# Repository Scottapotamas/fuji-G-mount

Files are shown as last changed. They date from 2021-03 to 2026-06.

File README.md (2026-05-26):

# Fujifilm G Mount
The Fujifilm G Mount is used by the Fujifilm GFX line of digital medium format mirrorless cameras.

Since the announcement in 2016, the GF lens ecosystem has been gaining popularity due to the superb optical performance, high megapixel camera bodies (GFX100), and low cost (well... compared to other MFD systems).

One minor challenge compared to most existing lens ecosystems - **all GF lenses are fly-by-wire**. Sensing user interaction with the aperture or focus rings, and commanding the iris and focus mechanisms will require computer control. Additionally, lenses such as the 110mm f2 and 250mm f4 have floating optical elements which require power/control from the body in order to become optically valid.

____

My long-term photography/hobby goals are rather ambitious; *build a film camera from scratch using modern lenses*. A 120 'body' for my GF lenses feels like the right kind of wrong...

## Aims

- [x] Document the mechanics of the G Mount sufficiently to create native-compatible mounts from scratch.
- Reverse-engineer & document the communications between the lens and body:
  - [x] Pinout for the electrical contacts in the lens mount,
  - [ ] Power supply requirements for lenses,
  - [x] Sniff the communications between the lens and camera, and document any specifics if possible.
- [ ] Write a library capable of parsing lens data (in both directions) in real-time.
- [x] Create an interface PCB which pretends to be a GFX camera - powers and controls an attached lens, can read lens info and focus/iris ring feedback.

## Prior Art?

At time of writing, no publicly available information about the mount's mechanics could be found other than the flange distance and internal diameter.

Similarly, any electrical interface or protocol information is not in the public domain.

> There's a good chance the Fuji X-mount uses a similar protocol or structure. Couldn't find any information for that either...

Several active (3rd party) lens adaptors *are* on the market, allowing smart control over Canon EF, Contax C645, and others. Therefore we can guess at least three different groups have successful implementations with varying levels of functionality.

## What's the plan

- [x] Buy a genuine Fujifilm extension tube [MCEX-45G WR](https://fujifilm-x.com/global/products/accessories/mcex-45g-wr/) to act as a ground-truth mechanical mount.
   - The absurd $500AUD pricepoint is painful, but won't risk my camera or lenses. I managed to get 25% off MSRP.
   - I could use one of the $150AUD Viltrox clone extension tubes later on, but I want an accurate first-party reference to build against.
- [x] Create detailed 3D models of the male and female mount geometries, identify screws/springs/gaskets used. Refer [`/mechanical`](/mechanical).
- [x] Dissemble the extension tube, design a replacement 'cylinder' to mount the genuine mounting faces onto. Or just seal it's fate and drill a hole in the adaptor...
   - Expose the lens and body electrical contacts through a loom or connector - ideally each side can be separated at will for easier debugging.
- [x] Map the electrical connections between the body and lens, create rough specs for power rails, determine the style of communication and electrical implementation(s) in use. Refer [`/electrical`](/electrical).
- [x] Assuming no strange electrical interfaces are used, connect the logic analyser/scope and build out a corpus of messages sent between the lens and body.
  - Refer [`/protocol`](/protocol) for notes.
  - Capture control ring, iris closure, focus motor on GF110 to compare against 45mm findings.
- [ ] Write a basic library implementation with unit tests against captured packets
   - [ ] Connect a micro running the library in real-time to the body, see what works/doesn't.
   - [ ] Connect micro to lens, see if setting iris or focus is possible

## What have we learnt

- Enough to successfully make a [GF mount adapter for the Fuji MK series S35 cine-zooms](https://github.com/Scottapotamas/fuji-mk-zoom-to-GF-mount).
- Protocol behaviour for a subset of packets: 
  - Aperture index and relative focus ring rotations sent from the lens to the camera
  - Closing the iris
  - Commanding absolute focus motor position
  - Some hazy details on the packet shapes

# References & Acknoledgements

- A [large mirror of firmware updates](https://u.pcloud.link/publink/show?code=kZRGzJXZA5zjOTgVm2FJjdvTIG1UekBLWefV#/filemanager?folder=7261419858) here by [Manzur Fahim on DPreview](https://www.dpreview.com/forums/threads/fujifilm-gf-lens-firmware-not-available-anymore.4824834/post-68549141).

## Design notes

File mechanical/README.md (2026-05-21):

# GF Mount Notes

This section covers the mechanical specifics involved in mounting a lens/body to existing GF mount lenses/bodies.

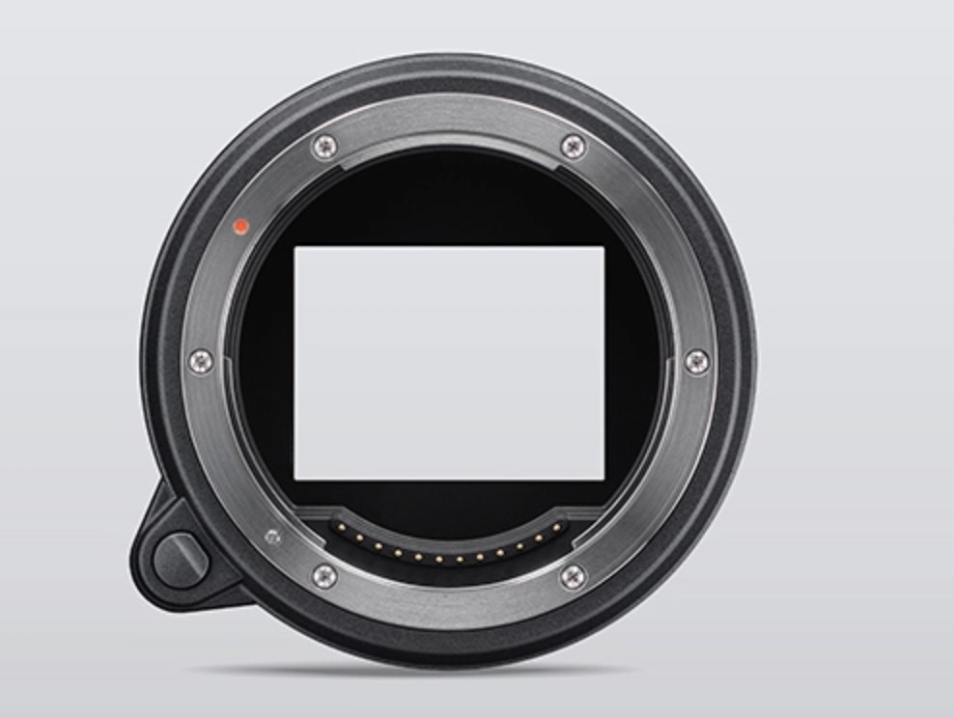
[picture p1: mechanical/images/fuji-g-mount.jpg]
fuji-g-mount


Where possible, 3D models strive for accuracy against first-party geometry, but due to the complex nature of some parts there is no guarantee of dimensional or tolerance perfection.

Additionally, while the models for machinable parts are accurate, little is known of the specification of the various screws as most are smaller than I'm able to accurately identify.

>  Custom fastener choice is recommended if mounting to custom assemblies.

## Mounting Faces

Measured off a disassembled MCEX-45, the front and back face 'flange' parts are all that's required to mechanically couple with existing GF mount hardware.

The design and manufacture of the external mounting faces with the 45mm extension tube is externally identical to the geometry on the GF45 and GFX50R.

> Models match first party parts more accurately than required for 3rd party mounts. The internal geometry and stepped internal faces can be simplified.

The two mating parts were tested for mechanical compatibility and tolerance with a physics simulation, and tolerances in the mated 3D models match the physical mounts checked with a spring-steel feeler-gauge.

Renders below:

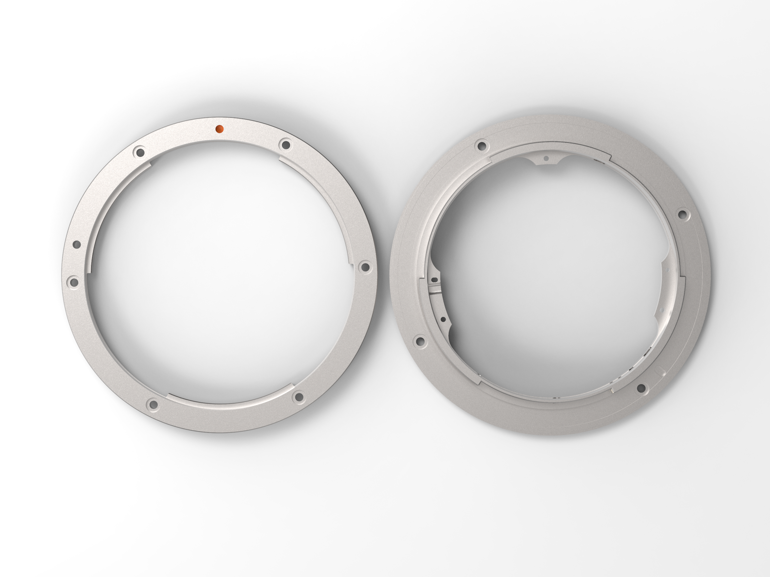
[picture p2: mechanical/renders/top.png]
top


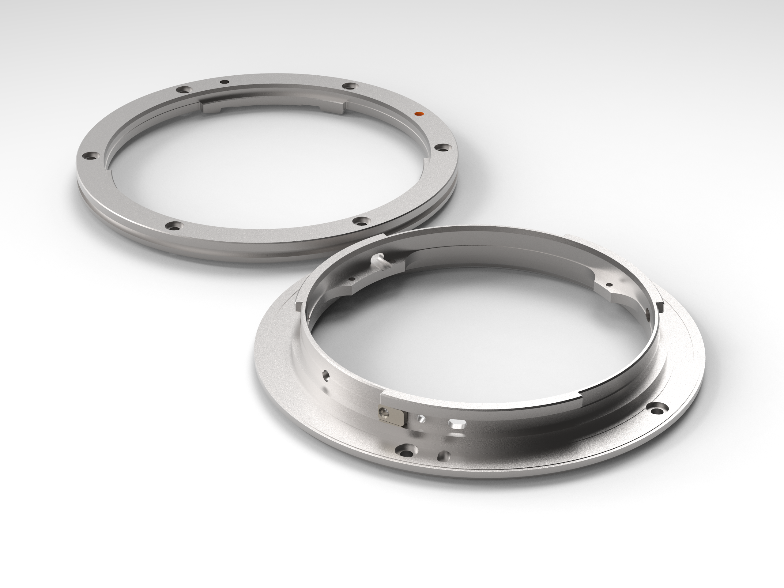
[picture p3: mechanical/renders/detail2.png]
detail2


Based on the part's surface finish and geometry, it's assumed that the lens mount 'male' is 4-axis machined, or likely turned on a lathe with live tooling.

The body mount has internal features which suggest casting, with post-machining of the front face and internal + external cylindrical faces.

The body mount has a thin (0.3 mm) stainless shim with bent metal tabs to provide preload against a mating lens. This shim is modelled but does not feature accurate tab bends (just do it by hand).

As a general note, it's probably cheaper to cannibalise the mounts from first party extension tubes, than it would be to send a pair for CNC machining due to the complicated geometry.

> When I 3D printed these they mounted fine, but the tolerances were a bit tight for brass machined mounts.
>
> Might be worth spot-checking some of the critical diameters again to better understand expected tolerances 

## Electrical Contacts

The contacts are also provided as a reference drawing, and in DXF format suitable for use with PCB design software to create custom pin array boards.

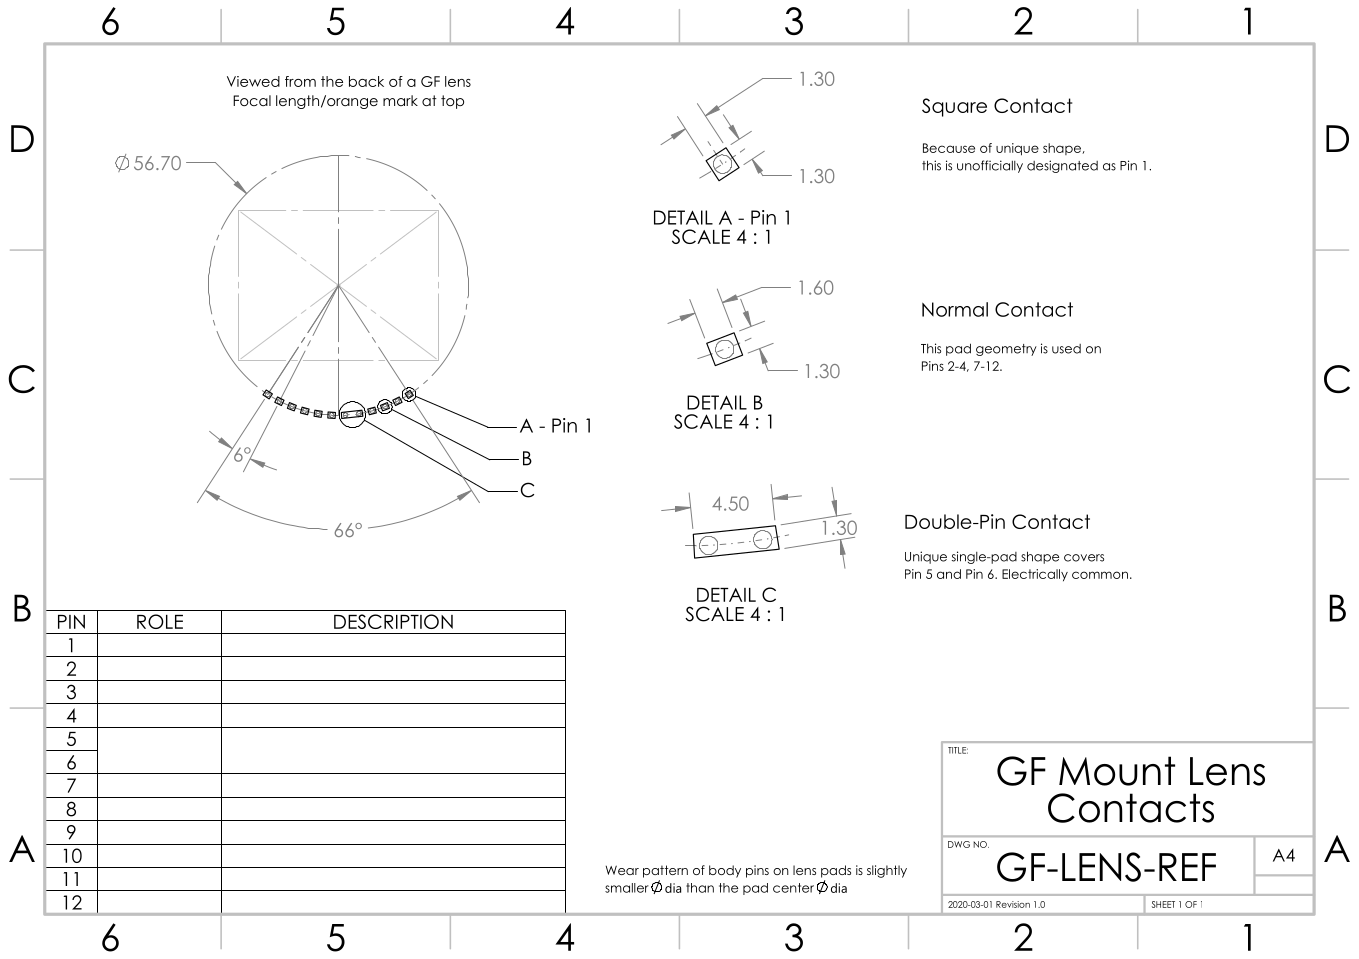
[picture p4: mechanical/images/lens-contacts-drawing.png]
lens-contacts-drawing


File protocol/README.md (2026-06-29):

# GF Protocol Notes

Sniffing of the communications between the body and lens is achieved with a modified MCEX-45G, and builds from the basic electrical analysis described in [the electrical README](/electrical).

This document has been reworked several times as my understanding of the protocol has developed. Apologies for mixed 'exploratory log' and 'findings' which sometimes includes extra information.

**Logic Analyser Captures**

Useful trace files are committed to the `captures` folder. Most analysis was done against the GF45 dumps, with later checks against the GF110.

These files require Saleae's Logic 2 tool for viewing. It's freely available for download on their website [here](https://www.saleae.com/downloads/).

Specific packets or sections of interest are converted into a more digestible form and are saved in `/packet-captures` as hex encoded binary files.

# SPI Communication

We can make the assumption about the specific IN/OUT pins because there ares in the logic captures which show one-way initial send packets, and occasional one-way responses.

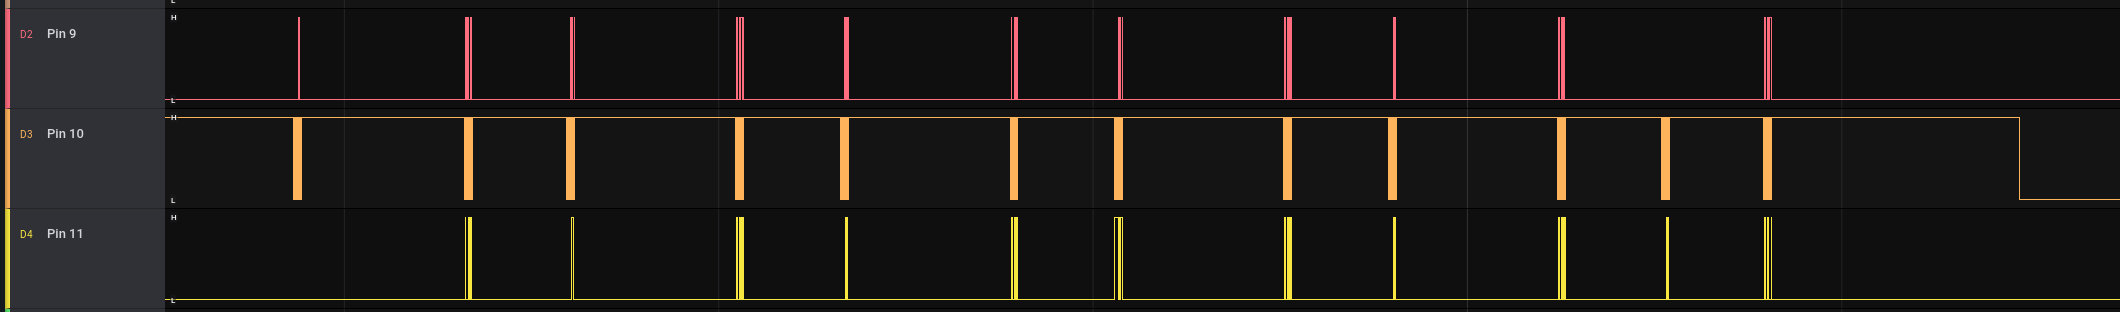
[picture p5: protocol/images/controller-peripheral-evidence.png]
controller-peripheral-evidence


Based on this, we can assume that:

- Pin 9 is body's DATA OUT line.
- Pin 10 is a 1.5MHz SPI-style clock signal.
- Pin 11 is the body's DATA IN line.

With this in mind, we now aim to identify the properties of the communications bus and determine that it uses typical SPI instead of some Fuji special sauce.

- A transaction consists of 32-bits at minimum
  - Almost all transactions are 32-bits long.
  - During startup, a pair of 1048-bit long transactions occur with a 3ms gap - these are the longest identified transactions.
  - As the division of  `1048` and the potential bits-per-transfer should be an integer, we can reasonably throw out `16` and `32` bit transfer sizes.

By manually inspecting logic captures, one example section helps determine the clock behaviour.

- The clock is high when inactive (CPOL = 1).
- Data is valid on the clock's trailing edge (CPHA = 1)
  - Demonstrated by the edges on the first falling edge, and on falling edges aligned to 8-bit sequences.
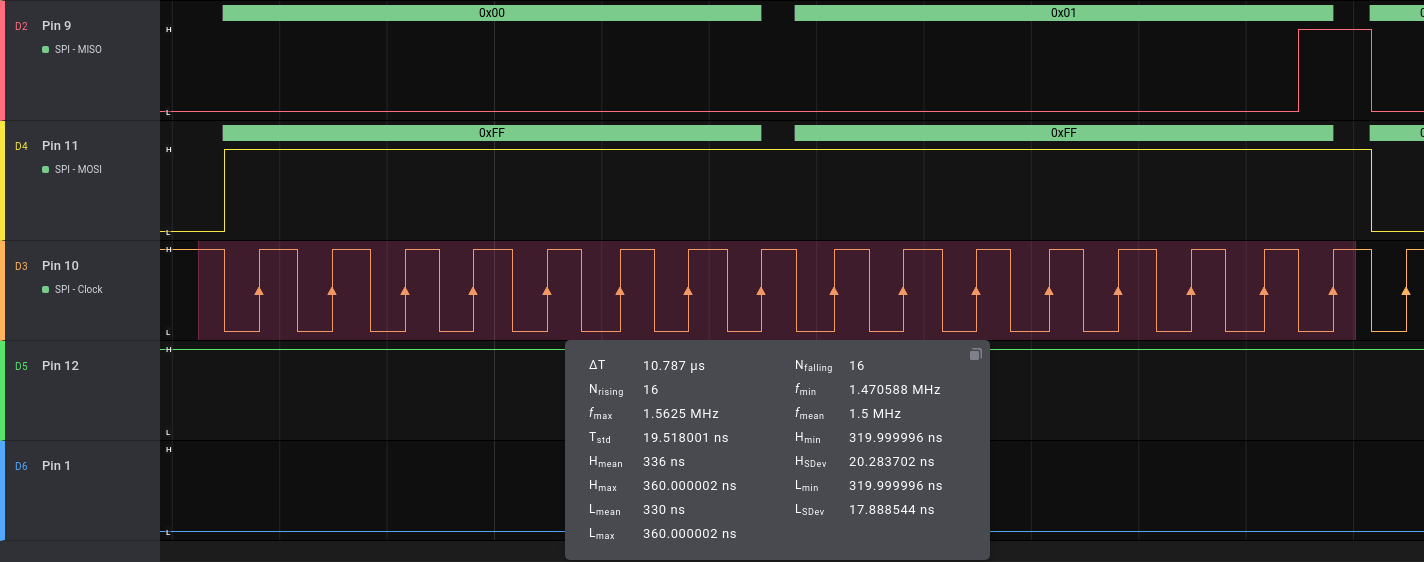
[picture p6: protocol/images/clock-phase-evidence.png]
clock-phase-evidence
    

As with typical SPI busses working with bidirectional transfers, there a fairly visible 1-packet delay between the body writing a field and the lens response.

When I'm listing tx/rx pairs in a given transaction in this document, that offset isn't included unless specified.

# Packet Exploration

While I've done this against/for the G-mount, poking at lens firmware update files and packet captures from [X-mount by Feiko Nanninga aka 'clonejo'](https://codeberg.org/clonejo/fuji-mount) allowed me to compare behaviour.

## Packet Structure

In wire-order most packets are 4-bytes of the form `payload payload command status` where useful payloads are typically big-endian signed 16-bit values or low value indexes.

Throughout the docs I've been treating the seemingly unstable last byte as some kind of checksum byte, but it's actually a structure with an extra field which is important for several command types.

### Message/Command

The command byte (third byte sent over the wire) includes an 'ack' flag at bit 7, i.e. `cmd | 0x80`, demonstrated on most currently known packets between tx and rx.

The total group of unique command bytes observed is below, entries with listed CMD or ACK values are in captured files. Currently the possible `0x00` command has not been observed.

| CMD | ACK/Response | Decode status |
| --- | --- | --- |
| — | `0x80` | Transport/status, not really decoded |
| `0x05` | `0x85` | Not documented/decoded |
| `0x06` | `0x86` | Not documented/decoded |
| `0x07` | | Not documented/decoded |
| `0x08` | `0x88` | Aperture/Focus and lens state feedback |
| `0x09` | `0x89` | Longer lens status bursts, not understood |
| `0x10` | `0x90` | Not documented/decoded |
| `0x0c` | `0x8c` | Aperture/focus control ring, mostly decoded. |
| `0x0f` | `0x8f` | Not decoded |
| `0x15` | `0x95` | Focus motor, mostly decoded |
| `0x16` | `0x96` | Not documented/decoded |
| `0x18` | `0x98` | Aperture setpoint, mostly decoded |
| `0x20` | `0xa0` | OIS. Not documented/decoded |
| `0x25` | | Not documented/decoded |
| `0x28` | `0xa8` | Not documented/decoded |
| `0x2a` | `0xaa` | Not documented/decoded |
| `0x32` | | Not documented/decoded |
| `0x3c` | | Not documented/decoded |
| `0x3f` | `0xbf` | Execute/latch, mostly decoded |

### Status Byte

Originally I was calling this a checksum due to how unstable it appeared across packets. Since then it's known to include some stateful information.

Using all the captured packets, de-duplicating and then sorting on 'command byte' and payload to find different header bytes for the same packet.

- Also filtered out all 'readout' packets that are an artifact of the SPI behaviour `00 00 00 00`.
- Assuming packets from the body and lens use the same behaviour, but the corpus tracks which device/trace the packets are seen in.

Looking over the headers, there were some under-represented bits on repeated packets with different final-bytes.

**Bit 0 is always low.** This seems to hold for *all* transactions I've captured (89,984 at time of observation). 

Luckily,  `09 00 88`  shows that **rx and tx directions can have the same final byte for an identical payload** it's less likely there's a 'camera' or 'lens' style send/recv bit in the field. This also means it's less likely that both sides are maintaining some shared incremental packet count.

The focus and iris settings use the same `0c` command byte, but when looking at the **top two bits** of the last byte, 

- Iris ring `0x0c` packets are always(?) `upper = 0` across 100+ examples.
- Focus ring `0x0c` packets are always(?) `upper = 2` across 600+ examples.
- For focus motor `0x15` packets, the upper bits evenly distribute with `00`/`01`/`10` but never `11`. 
- Execute/sync commands are `11`.

Looking at behaviour around 'most understood' packets for iris and focus there is a fairly obvious pattern in the remaining bits:

| Direction | CMD | Prefix | Upper-2b values | Final bits 1..5 values |
| --- | --- | --- | --- | --- |
| RX | `0x0c` | `00 02 0c` | 2, 0 | `1a`, `19` |
| RX | `0x0c` | `00 03 0c` | 2, 0 | `0a`, `09` |
| TX | `0x0c` | `00 00 0c` | 2, 0 | `19`, `18` |
| RX/TX | `0x15` | `01 f4 15` | 0, 2 | `0c`, `0d` |
| RX/TX | `0x15` | `03 6b 15` | 0, 2 | `1d`, `1e` |
| RX/TX | `0x15` | `01 23 15` | 1, 2 | `11`, `11` |

The table shows that with the upper bits taken into account, the remaining data in the trailing byte has a stable value and a one-bit field that varies.

Looking at the larger set of captures, only 80 of 5153 deduplicated packets have multiple tail byte options for an otherwise identical packet. When taking the upper two bits into consideration, the remaining 5 bits have fewer variations and they aren't random as expected for a signature or checksum.

This immediately **rules out sequence numbering** or global counting behaviours. ~~And I'm now convinced the remaining field(s) do not represent any kind of checksum or signature.~~

Looking over the full set of packets, the remaining byte's bit 1 (or bit 0 of the 5-bit field) seems to impact the largest number of packets, responsible for the variation in 45 of 80 relevant packet examples. So pulling this bit out during review/parsing and trying to find correlations in burst sequences or with hardware behaviours is a good next step.

| Prefix | Bits 1..5 variants | After masking bit 0 | Notes |
| --- | --- | --- | --- |
| `00 00 08` | `0x10`, `0x11` | `0x10` | Common idle/status request shape  |
| `08 00 95` | `0x14`, `0x15` | `0x14` | `0x95` ACK family |
| `08 00 89` | `0x1c`, `0x1d` | `0x1c` | `0x89` ACK family |
| `00 01 08` | `0x00`, `0x01` | `0x00` | Variant of `0x08`? |
| `00 00 0c` | `0x18`, `0x19` | `0x18` | Focus-ring / aperture-ring family |

It's a bit hard to tell right now if the next bit is independent, it's another two-bit field instead of just bit-1, or if it's a larger enum/status field? For the limited set of `88` packets here, bit 2 appears high in the longer sequences?

> I couldn't figure this out after lots of different attempts, and resorted to analysis of lens update files to find clues

The **5-bit check value is computed as a truncating sum of 5-bit chunks** over the packet, including the upper2 bits in the last byte.

```
g0 = b0[7:3]
g1 = b0[2:0] : b1[7:6]
g2 = b1[5:1]
g3 = b1[0]   : cmd[7:4]
g4 = cmd[3:0]: tag2[1]
g5 = tag2[0]
```

Then `check5 = (g0 + g1 + g2 + g3 + g4 + g5) & 0x1f`

Demonstrated on some packets:

```
00 00 08 20
tag2   = 0
check5 = 0x10
tail   = 0x20

00 02 0c 32
tag2   = 0
check5 = 0x19
tail   = 0x32

00 01 0c 92
tag2   = 2
check5 = 0x09
tail   = 0x92

00 00 3f c6
tag2   = 3
check5 = 0x03
tail   = 0xc6
```

This appears correct for 100% of `602,863` captured packets.

## Status Packets

When the camera is powered on but is otherwise sitting idle, we see a burst of transactions occur every 40ms. These packets represent the bulk of 'noise' when watching packet traces.

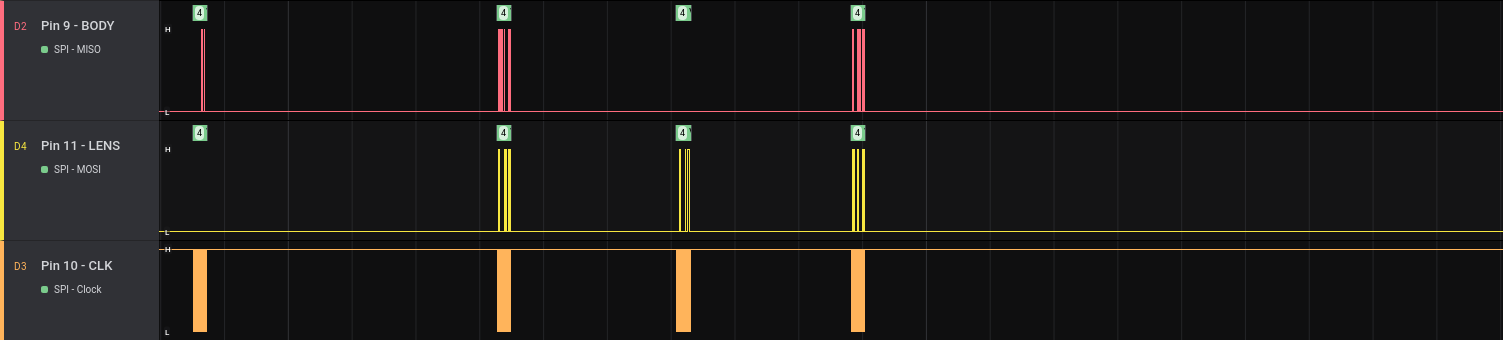
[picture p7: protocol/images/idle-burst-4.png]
idle-burst-4


| Transmission # | Camera | Lens |
| --- | --- | --- |
| 1 | `0x00 0x00 0x08 0x20` | - |
| 2 | `0x?? 0x10 0x80 0x??` | `0x08 0x00 0x88 0x32` |
| 3 | - | `0x03 0x80 0x08 0x3C` |
| 4 | `0x08 0x00 0x88 0x??` | `0x?? 0x00 0x80 0x??` |

The `0x08` packets from the body are requesting updates from the lens like aperture or focus control ring values, motor feedback etc.

This packet is also seen in the normal polling/idle traffic with tag 0, polled by the body with `00 00 08 20`. The lens-side non-ACK response should be treated as a compact status/event bitfield, but the meaning of these bits isn't entirely known yet.

The low seven bits of payload `b1` appear to identify pending follow-up requests:

| Lens response payload | Follow-up body poll | Interpretation |
| --- | --- | --- |
| `00 08`, `00 88` | `00 00 0c b2` | Focus ring / focus-control readout pending |
| `00 10`, `00 90` | `00 00 0c 30` | Aperture ring / aperture mode readout pending |
| `00 00`, `00 80` | next normal tag-0 poll | No specialised data pending |
| `00 02`, `00 82` | Status/detail path such as `0x0f` or tag2 feedback | Active/detail/actuation-status candidate |

`b1 bit7` might be a scheduler or response-phase marker. It not clear if it's a  dirty/valid/busy bit yet. ACK `0x88` tag-0 packets are transport acknowledgements and should be excluded ignored as part of the lens-state polling.

On every third burst, we have 2 additional transactions for a 6 transaction 'group'. This happens every 120ms.

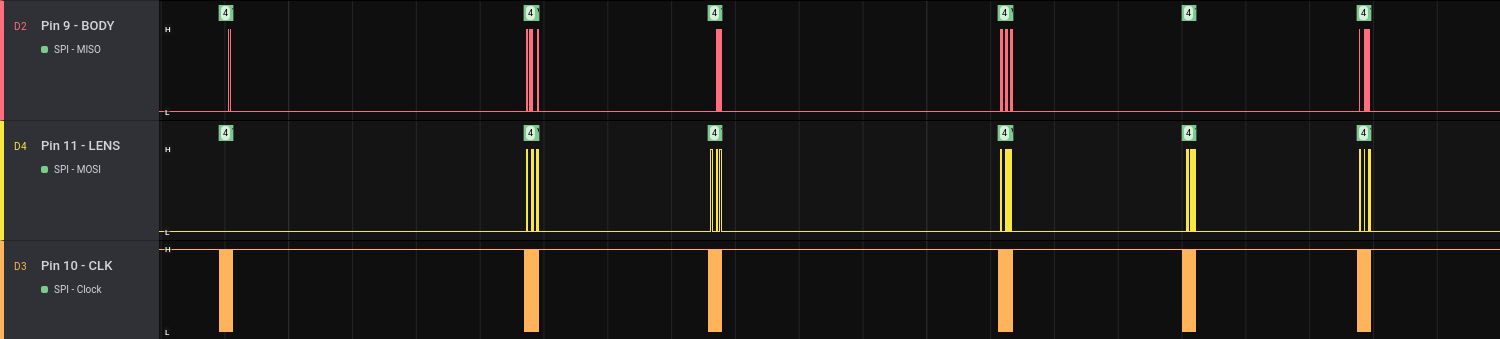
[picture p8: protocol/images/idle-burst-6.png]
idle-burst-6


These bursts add the `0x09` request `00 00 09 a6`. 

| Transmission # | Camera | Lens | Notes |
| :--- | --- | --- | --- |
| 0 | `00 00 08 20` | - | Normal `0x08` status request |
| 1 | `n 10 80 ??`  | `08 00 88 32` | Tagged transport/status + ACK |
| 2 | `00 00 09 a6` | `xx xx 08 ??` | Body requests `0x09`; lens returns normal `0x08` status due to pipeline delay |
| 3 | `n 00 88 ??`  | `n 00 89 ??`  | ACK path for previous `0x08`/`0x09` traffic |
| 4 | - | `00 xx 09 ??` | Lens returns the non-ACK `0x09` payload |
| 5 | `08 00 89 b8` | `n 00 80 ??`  | Body ACKs the `0x09` response |

The response seems to be small values, examples:

``` 
00 11 09 96
00 12 09 b8
00 13 09 98
00 14 09 ba
00 15 09 9a
00 16 09 bc
```

`00 0f`, `00 10` payloads are seen only 5 times in the capture sets, around startup transitions.

The payload value seems relatively stable/constant across most captures, when it does change it seems to toggle between adjacent values, e.g. `00 13 <-> 00 14`, `00 14 <-> 00 15` rather than jumping around.

> TODO: Work out what this actually represents?

## Identification Packets

After the camera is powered on, a series of `131B` transactions occur (each sent twice 3ms apart). Both transmissions appear to have identical payloads.

### GF45mm

The first transaction starts the first two bytes with `0x00 0x00`, and ends with `0xAF`.

The second transaction starts with `0xFF 0xFF` and ends with `0xAD`.

The payload (in hex) is:

```
4c52 3130 3641 0000 4653 534e 5730 3036
4746 3435 6d6d 4632 2e38 2052 2057 5200
0000 0000 0000 0000 0000 0000 0000 0000
0000 0000 0000 0000 0000 0000 0000 0000
0000 0000 0000 0000 0000 0000 0000 0000
3234 3033 3338 3636 3035 0156 0100 0100
0100 0100 c801 0000 0000 0000 0000 0000
0000 0000 0000 0000 0000 0000 0000 0000
```

These transactions are from the lens to the body and **describe the lens**. 

- The first section of data is ASCII: `LR106A  FSSNW006GF45mmF2.8 R WR` 
  - The first section, `LR106A` is also in the lens firmware as a string with `FSSNW006`. Refer to `/firmware/identity-strings.md`.
  - The last half is obvious obvious, the lens is officially labelled as  `GF45mmF2.8 R WR`.
- The second block of data in the payload is `2403386605 V` `È` in ASCII, which isn't immediately obvious
  - TODO work out what this data means?

### GF110mm

The first transaction starts the first two bytes with `0x00 0x00`, and ends with `0x0B`.

The second transaction starts with `0xFF 0xFF` and ends with `0x09`.

The payload (in hex) is:

```
4c52 3130 3441 0000 4653 534e 5731 3034
4746 3131 306d 6d46 3220 5220 4c4d 2057
5200 0000 0000 0000 0000 0000 0000 0000
0000 0000 0000 0000 0000 0000 0000 0000
0000 0000 0000 0000 0000 0000 0000 0000
3035 4330 3030 3234 0000 0160 0110 0110
0110 0110 c801 0000 0000 0000 0000 0000
0000 0000 0000 0000 0000 0000 0000 0000
```

These transactions are from the lens to the body and **describe the lens**. 

- The first section of data is ASCII: `LR104A  FSSNW104GF110mmF2 R LM WR`
  - `LR104A` and `FSSNW104` are identifier strings. Refer to `/firmware/identity-strings.md`
  - The last half is obvious, the lens is officially labelled as `GF110mmF2 R LM WR`.
- The second block of data in the payload is `05C00024` `È` in ASCII
  - TODO work out what this data means

### GFX50R

> These body identification packets occur somewhat later than the lens identification packets, and only when the `GF110mm` is mounted.

The first transaction starts the first two bytes with `0x00 0x00`, and ends with `0x19`.

The second transaction starts with `0xFF 0xFF` and ends with `0x17`.

The payload (in hex) is:

```
5350 5833 0000 0000 0000 4746 5820 3530
5200 0000 0000 0000 0000 0000 0000 4746
5820 3530 5200 0000 0000 0000 0035 3933
3533 3433 3833 3633 3131 3831 3131 3339
3744 3031 3031 3130 3834 3102 2001 3501
0001 0001 0000 0000 0000 0000 0000 0000
0000 0000 0000 0000 0000 0000 0000 0000
0000 0000 0000 0000 0000 0000 0000 0000
```

These transactions are from the body to the lens and **describe the body.** 

- The first section of data is ASCII: `SPX3` `GFX 50R` `GFX 50R` (whitespace trimmed)
  - Unsure of what `SPX3` represents.
  - The repeated pair of `GFX 50R` string sequences match the body under test.
- The second section of data is unknown.
  - `59353438363118111397D010110841   5` in ASCII, with some unprintable bytes
  - Unknown data

### X-Mount

The same behaviour is demonstrated the clonejo captures:

```
LX210A  FLZGW104XF18-55mmF2.8-4 R LM OIS
LX212A3 FLZGF020XC50-230mmF4.5-6.7 OIS II
LX233B  FLZGW435XF70-300mmF4-5.6 R LM OIS WR

LX42      X-T2                X-T2
```

## Aperture Control Ring

From the large set of lens iris change captures, a pattern across the captures started to be more obvious in the packets sent from the lens to the body (i.e. body rx):

```
rx 00 02 0c xx
rx 00 03 0c xx
rx 00 04 0c xx
...
rx 00 10 0c xx
...
rx 00 16 0c xx
```

The body requests it with `00 00 0c xx` and specifically clocks a transaction for readout as `tx 00 00 00 00` is observed during these packets. It's currently unclear if there's a 'data ready' or 'state dirty' flag that triggers the poll.

The `0c` command is also used for focus ring incremental readout, but the **top two bits of the last byte are always low for iris ring packets**, `bit 6..7 = 00`.

Sequenced something like this:

```
tx 00 00 0c ??       body asks for aperture-index state
rx 00 XX 0c ??       lens reports aperture ordinal value
tx/rx n 00 8c ??     ACK
rx n 00 80 ??        unsure, final status/result
```

If I encoded a hypothetical index to each accessible f-stop position on the GF45mm control ring (and retrospectively 1-index it):

```
01 = f/2.8
02 = f/3.2
03 = f/3.6
04 = f/4
05 = f/4.5
06 = f/5
07 = f/5.6
08 = f/6.4
09 = f/7.1
0a = f/8
0b = f/9
0c = f/10
0d = f/11
0e = f/13
0f = f/14
10 = f/16
11 = f/18
12 = f/20
13 = f/22
14 = f/26
15 = f/29
16 = f/32
```

This seems to be validated with actual sniffed f-stop tests:

```
f2.8 -> f3.2   rx 00 02 0c 32
f3.2 -> f3.6   rx 00 03 0c 12
f3.6 -> f4.0   rx 00 04 0c 34
...
f29 -> f32     rx 00 16 0c 06
```

On the GF110mm which has f2.0 to f22 range, there's the same number of third-stops over the range, they map against index the same way.

> There are lenses in the GF ecosystem such as the 80mm f1.7 to 22 which should have more configurable apertures? Are there lenses with fewer?

Plotting the values during the 'sweep' captures shows the transitions.

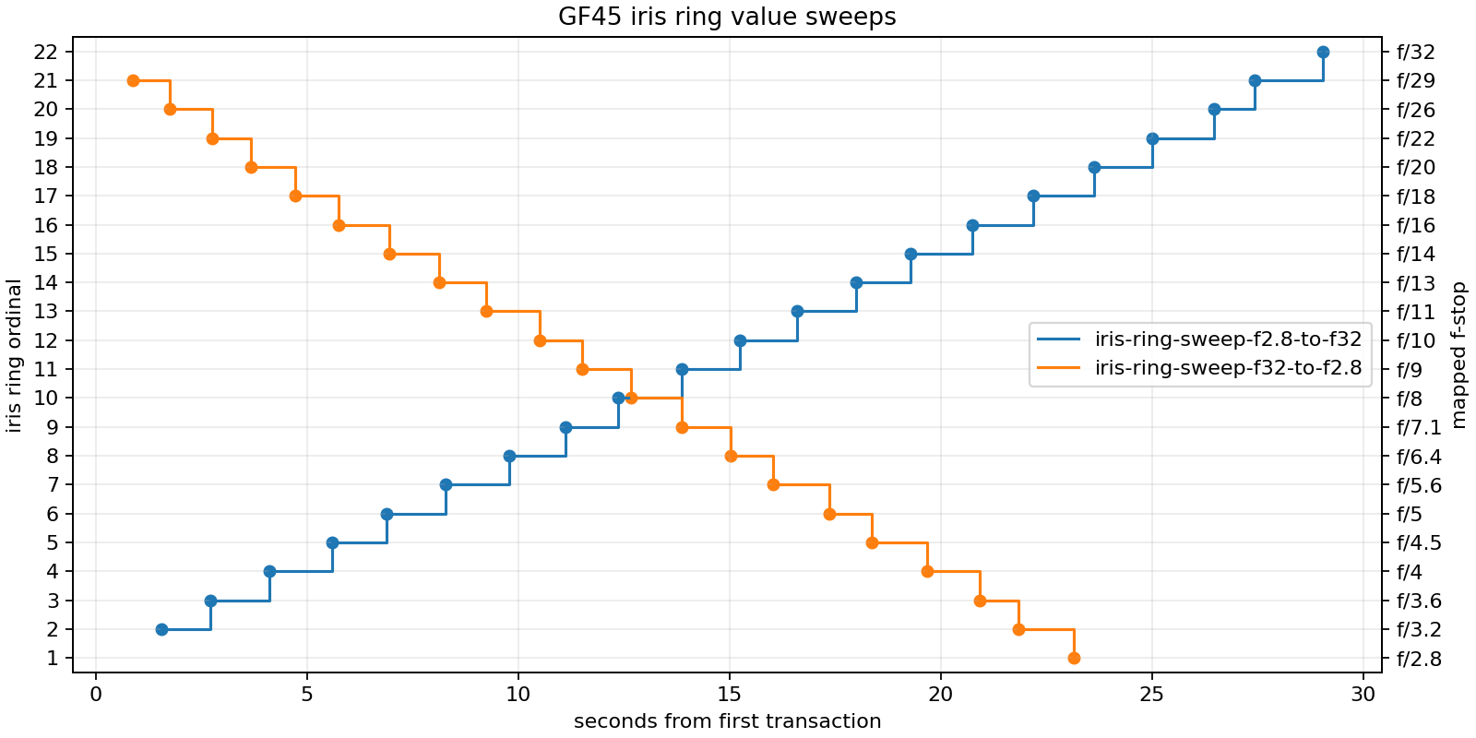
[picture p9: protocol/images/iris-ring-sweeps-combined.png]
45mm lens iris against index value, increases in clear steps over time during sweep capture


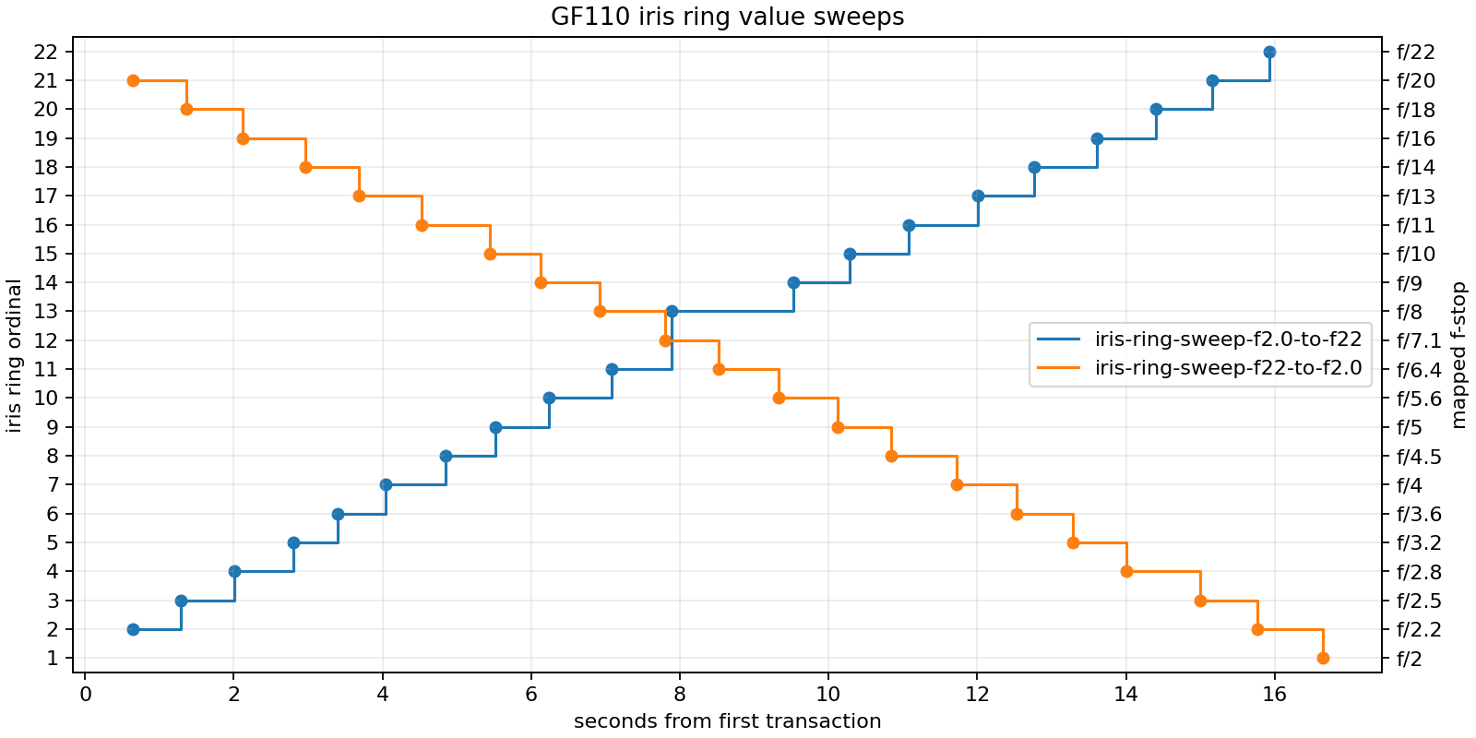
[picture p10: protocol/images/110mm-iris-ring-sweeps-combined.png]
110mm lens iris against index value, increases in clear steps over time during sweep capture


Now there's a known packet behaviour `00 XX 0c YY`, poking at the relationship(s) to the final byte may be easier?

A larger observation example set:

```
00 01 0c 10
00 02 0c 32
00 03 0c 12
00 04 0c 34
00 05 0c 14
00 06 0c 36
00 07 0c 16
00 08 0c 38
00 09 0c 18
00 0a 0c 3a
00 0b 0c 1a
00 0c 0c 3c
00 0d 0c 1c
00 0e 0c 3e
00 0f 0c 1e
00 10 0c 00
00 11 0c 20
00 12 0c 02
00 13 0c 22
00 14 0c 04
00 15 0c 24
00 16 0c 06
```

The lenses also have a `A` automatic mode selection position and a `C` custom position for camera-side control over the aperture. I forgot to capture these with the GF45, but did with GF110.

When entering AUTO there was less/no *obvious* packet behaviour as it also doesn't allow dof-preview.

I noticed a 'new' `00 00 0c 30` packet was visible, but later review shows it in other manual iris sweeps as well.

There wasn't a visible change when clicking the ring to custom mode (camera showed f4). There was a notable change of `00 80 08 24` packets to `08 80 08 26` though?

> On X-mount, or the GF cine-zoom for Eterna, we might see different behaviour as they support de-clicked behaviour?
>
> i.e. `XF16-55mmF2.8 R LM WR II` or `XF18-120mmF4 LM PZ WR`

> TODO:
>
> - Additional captures sweeping through A and C on both lenses
> - Pull out the lens ring A/C fields to a known/confirmed state

## Focus Control Ring

The focus ring is also fly-by-wire. Because the ring isn't marked and is free to rotate infinitely, there's no easy way to capture known step values.

So a handful of captures were done to cover a range of possible packet scenarios in both manual focus mode (lens motor activates on turn), and autofocus mode where the ring isn't typically used.

- Captures with small, longer, and >revolution movements made continuously in each direction
- Captured back and forth movements, expecting to see a rough sine/triangle position trace 

After looking through the captures for unique/different packets, a packet from the lens seems to be a viable candidate for a big-endian 16-bit value:

```
rx 00 01 0c 92    +1
rx 00 04 0c b6    +4
rx 00 08 0c ba    +8

rx ff ff 0c 8c    -1
rx ff fb 0c 88    -5
rx ff f8 0c a6    -8
```

- Clockwise captures are positive values, counterclockwise are negative.
- They are relative values, showing larger values in the 'fast' rotation captures.
- They aren't published/polled at a different rate based on change.
- The behaviour appears the same on the GF45 and GF110mm lenses, even though the GF110 has a much longer throw.

The **body polls the increment value** with `00 00 0c b2`, and the lens responds two transactions later.

```
tx 00 00 0c b2       request ring state
rx 00 11 09 96       

tx 0e 00 89 a8
rx 0d 00 8c ac       ACK the 0x0c read

tx 00 00 00 00
rx 00 04 0c b6       ring delta = +4

tx 08 00 8c 84       ACK the 0x0c value?
rx 0e 00 80 02       Possible status update
```

The `0c` is also used for the iris control ring. For focus packets, the **top two bits of the last byte are always high** (`bit 6..7 = 11`).

In the captures where the manual focus mode was active and the motor would move, we see additional `0x15` packets which are documented in the focus motor section.

Extracting the values with timestamps and then plotting them and a running sum, gives convincing results.

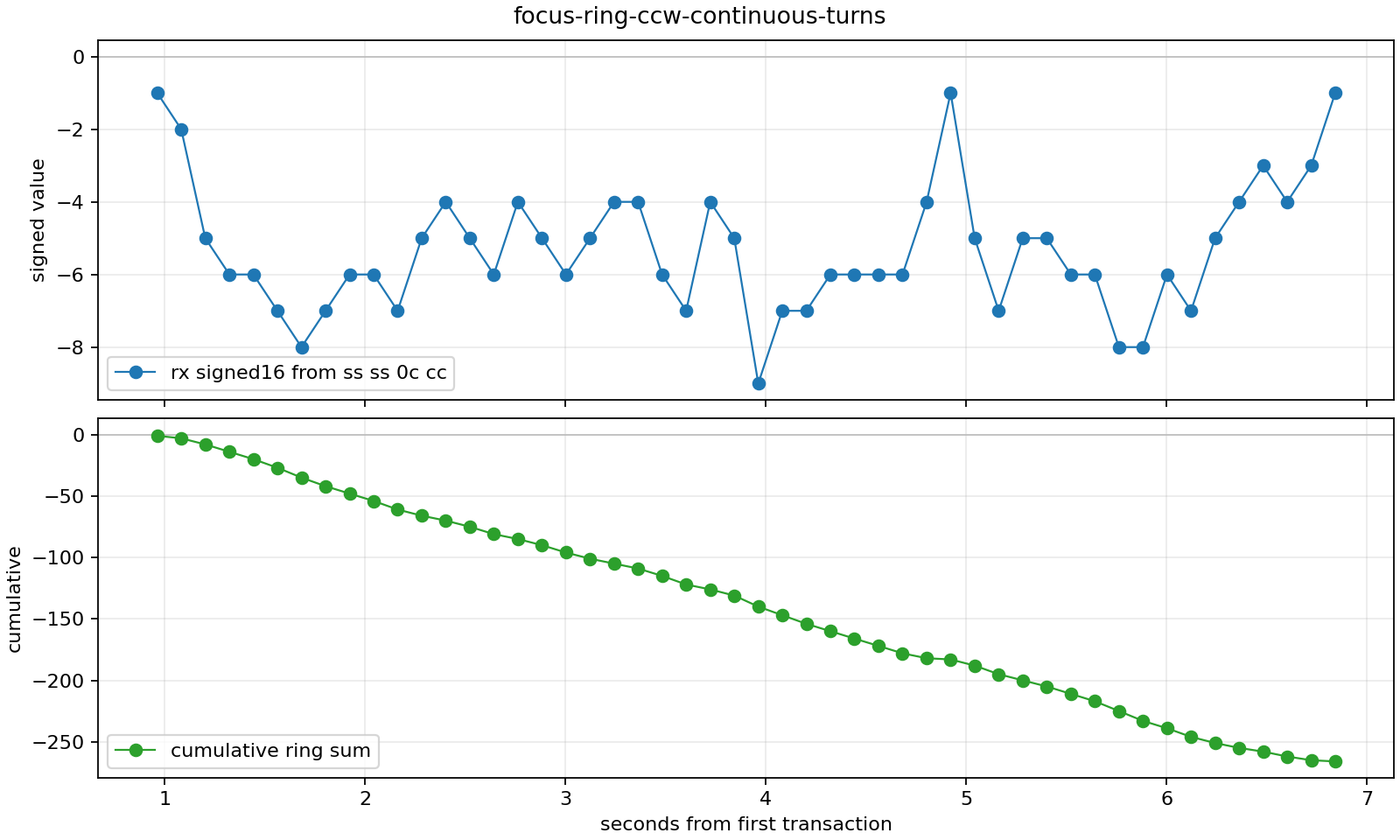
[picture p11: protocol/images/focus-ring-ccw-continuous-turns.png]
focus-ring-ccw-continuous-turns
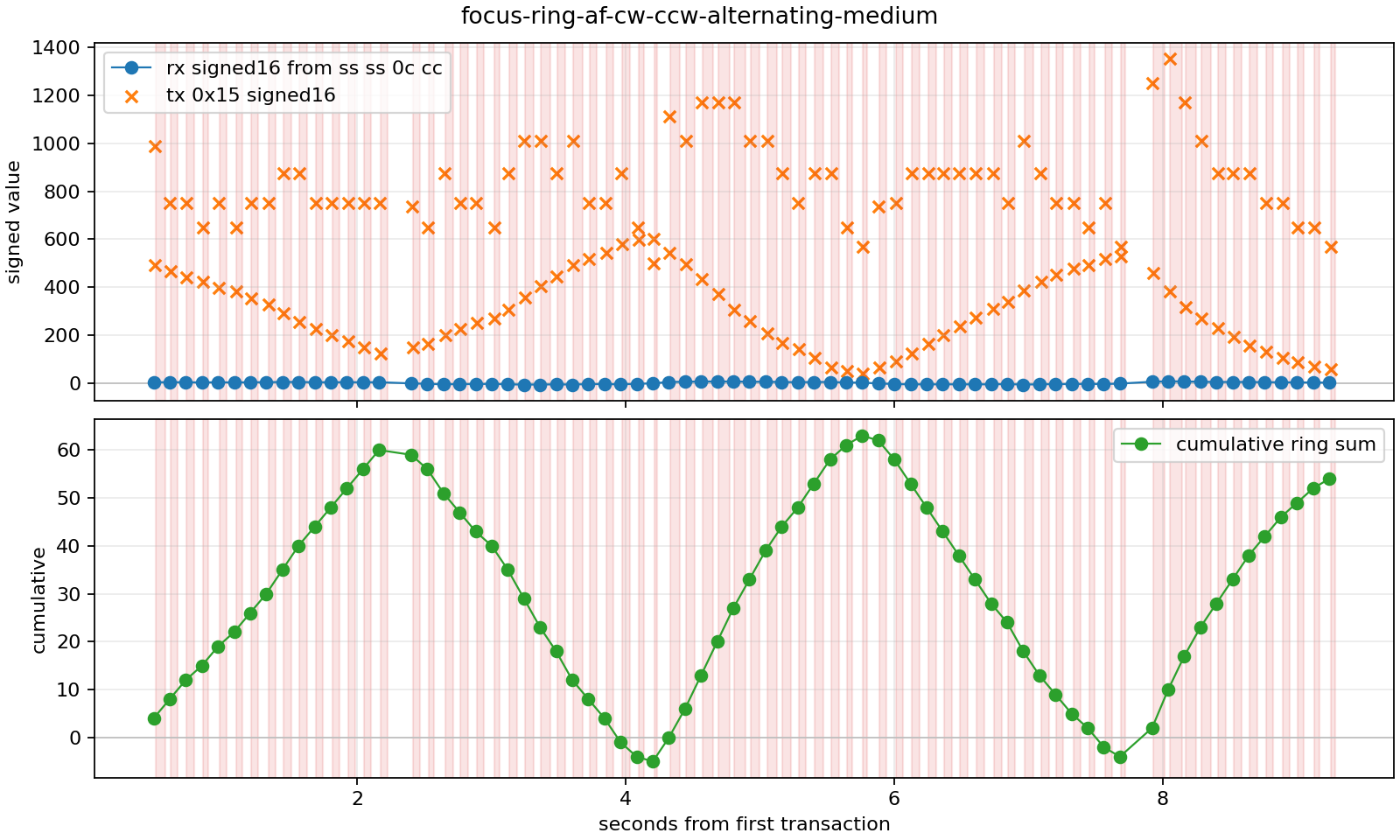
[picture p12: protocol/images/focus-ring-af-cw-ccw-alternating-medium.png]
focus-ring-af-cw-ccw-alternating-medium


Example packets that are useful for comparison:

```
# autofocus/non-actuating, clockwise continuous turns
rx 00 01 0c 92
rx 00 02 0c b4
rx 00 04 0c b6
rx 00 08 0c ba

# autofocus/non-actuating, counter-clockwise turns
rx ff ff 0c 8c
rx ff fd 0c 8a
rx ff fb 0c 88
rx ff f6 0c a4

# manual-focus/actuating, alternating direction
rx 00 04 0c b6
rx 00 03 0c 94
rx 00 05 0c 96
rx ff ff 0c 8c
rx ff fd 0c 8a
rx ff fb 0c 88
rx 00 06 0c b8
rx 00 07 0c 98
```

## Sync/Actuate Command

From the larger dump of iris closures, the packet `00 00 3f c6` is found just before the iris closes in all cases, and around focus events. Given it's always the same, and the lens echoes it, I think it's treated as a 'execute' or 'sync' event. 

The 'upper 2' of the final byte are `3` or `11b` for this packet.

The lens acks with `n 00 bf xx` i.e. `0b 00 bf f0` immediately before the falling edge on the iris status IO.

This behaviour doesn't occur when the control ring is rotated without dof preview on, or the focus control ring rotated in auto-focus modes.

The values being acted on appear to be staged beforehand (discussed in next sections).

## Aperture Drive

The setting on the lens control ring doesn't appear to be used internally by the lens, **the body commands the iris setpoint**.

Controlling the aperture blades without changing the control ring on the lens is doable in auto mode (and forcing auto-exposure to stop down/up) and in 'custom' mode where the body ring controls the f-stop target (with dof-preview active to force it).

The concept is proven with captures which have no `00 xx 0c cc` 'ring index' packets in the GF110 auto/custom tests, but `00 00 3f c6` execute commands and the falling edge on the iris IO are visible.

The command behaviours that I could find wasn't tightly correlated to the falling edges:

- `0x18` 'staging' commands, seen in GF110 `auto-aperture-dark-to-bright-to-dark` without motor `0x15` commands.
  - The `0x18` commands are not near the IO falling edge.
  - Acknowledged with `0x98`, sharing the same execute command.
  - Lines up with most of the GF45 iris edges as well.

The sequence is typically

```
tx <staged command>     0x18 family, carries target/move information
tx feedback/ack  		n 10 80 / n 00 98 path depending on family
tx 00 00 3f c6          execute/latch
rx <staged command>     lens ack of the staged command
tx n 00 95/98 ??        family-specific acknowledgement
rx n 00 bf ??           execute response
rx 00 00 3f c6          lens echo of execute shortly after the edge/handshake
```

I also noticed that the iris IO line negative pulse that occurs when stopping down/up takes an increasing amount of time based on the 'stop distance' in the transition. I suspect this signal might indicate 'iris OK' or similar. 

> In some captures there is some minor error as the camera delayed the command for the 'smoothed' simulated viewfinder brightness.

### Setpoint

The aperture setpoint seems to be encoded inside the `0x18` command with corresponding ack from the lens.

```
tx AA BB 18 CC
tx 00 00 3f c6
rx AA BB 18 CC
```

The values in captures are somewhat tied to third-stop increments due to the camera not allowing finer settings, but the pattern looks common to both lenses and is familiar to the control ring indexing:

```
10 00 18 a8 -> index 1
10 40 18 aa -> index 2
10 80 18 ac -> index 3
10 c0 18 ae -> index 4
11 00 18 b0 -> index 5
...
15 40 18 92 -> index 22
```

Where the GF45 index 1 = f/2.8 and 22 = f/32, and the GF110 index 1 = f/2.0, index 22 = f/22.

Numerically, the encoding could be described as:
```
index = ((BE16(AA BB) - 0x1000) / 0x40) + 1
```

> When a custom controller can drive the lens, it might be worth seeing if the iris supports finer setpoint resolution?
>
> Do any of the x-mount lenses/bodies have clickless iris or finer selection controls?

### Feedback

The body sends `00 01 08 82`, and the lens appears to return `<aperture_bitfield> 00 08 <tail>` which includes an index that correlates similarly to the control ring e.g. `00 -> f2.8` and `15 = f32` for GF45.

These have upper2/tag value of `2`. Firmware analysis shows the payload bitfield might be shaped like

```
uint8_t iris_index = b0 & 0x1f;
bool flag5 = b0 & 0x20;
bool flag6 = b0 & 0x40;
bool flag7 = b0 & 0x80;
uint8_t aux = b1;
```

Same behaviour on GF110. DoF-preview enabled sweep shows the ring, camera command and feedback aligning well.

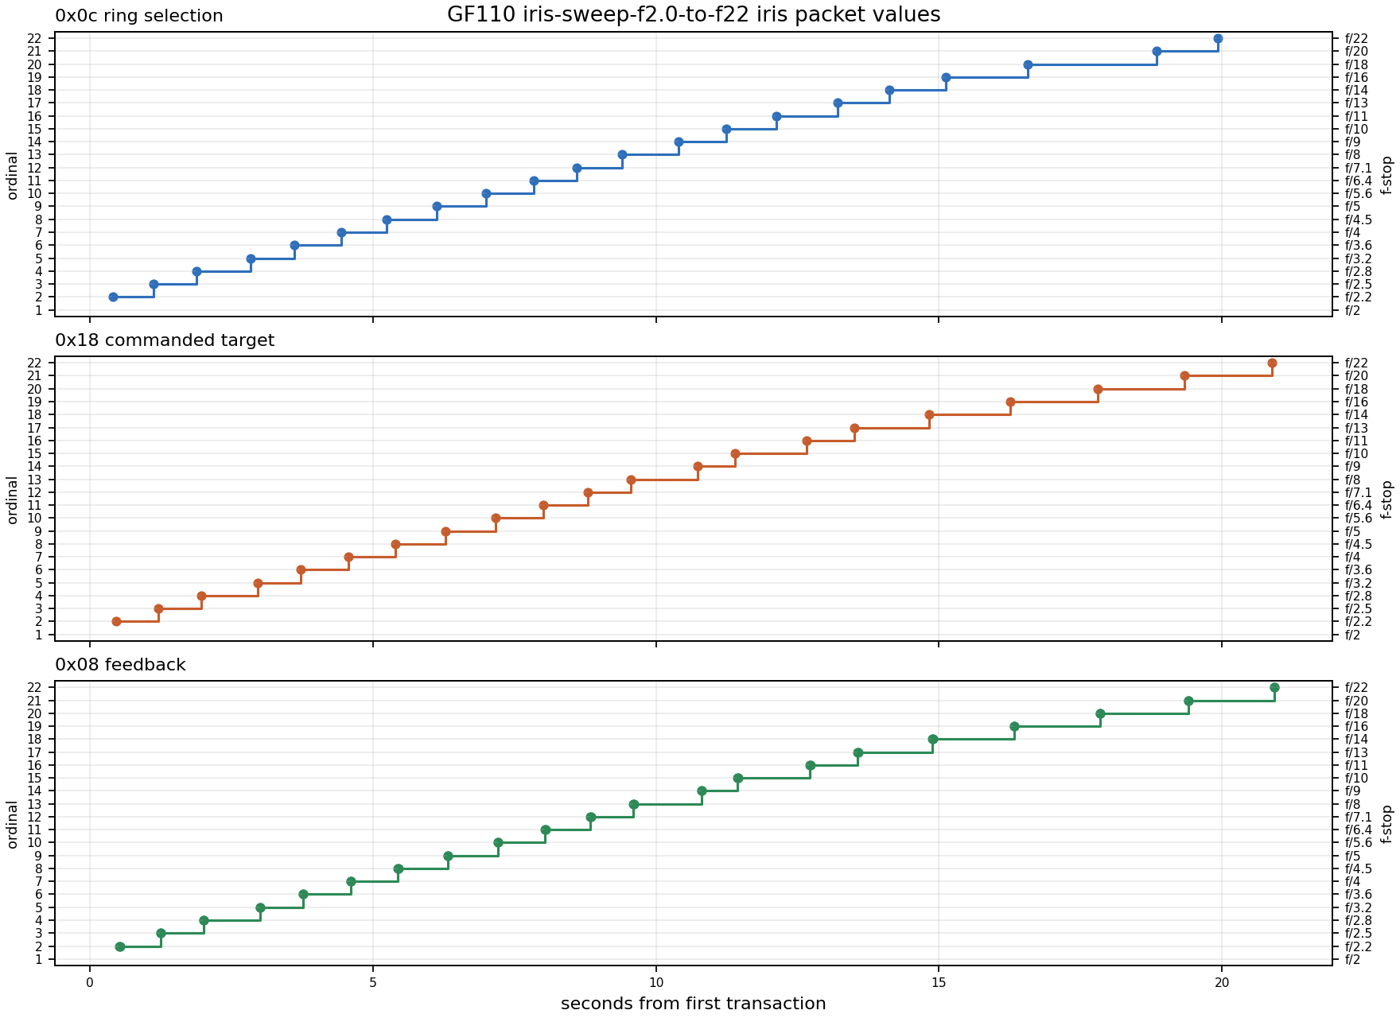
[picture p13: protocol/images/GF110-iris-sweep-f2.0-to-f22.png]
f2-f22 sweep with feedback plot matching user setting, body command and lens feedback


## Focus Motor Drive

Two digital lines (in captures CH1 and CH2) correlate to the focus behaviour, so inferring their purpose and correlation to data from these captures should also be doable.

We (from later passes) know the top-two bits in the last byte represent some kind of sequence/phase index. I've called it a 'tag' value here, as it seems to correlate to the behaviours.

### Packet Sequence

```
tx 03 dc 15 10       Tag 0, value 988 request
rx 00 00 00 00

tx 0f 10 80 1a       ?
rx 08 00 95 28       0x15 family ACK

tx 01 20 15 40       Tag 1, 288
rx 03 dc 15 10       Echo of Slot A request

tx 08 00 95 28       0x15 family ACK
rx 0f 00 95 62       0x15 family ACK

tx 01 ed 15 b2       Tag 2, target position 493
rx 01 20 15 40       Echo of 288 Tag 1 

tx 09 00 95 72       0x15 family ACK
rx 08 00 95 aa       0x15 family ACK

tx 00 00 3f c6       Execute/latch
rx 01 ed 15 b2       Echo of target position 493 Tag 2

tx 0a 00 95 ba       ACK/status
rx 09 00 bf e0       Execute ACK

tx 00 00 00 00
rx 00 00 3f c6       Echo of execute
```

This sequence is seen on both GF45 and GF110.

Plotting the values during a AF single-shot sequence for the captures using GF45 looks fairly reasonable.

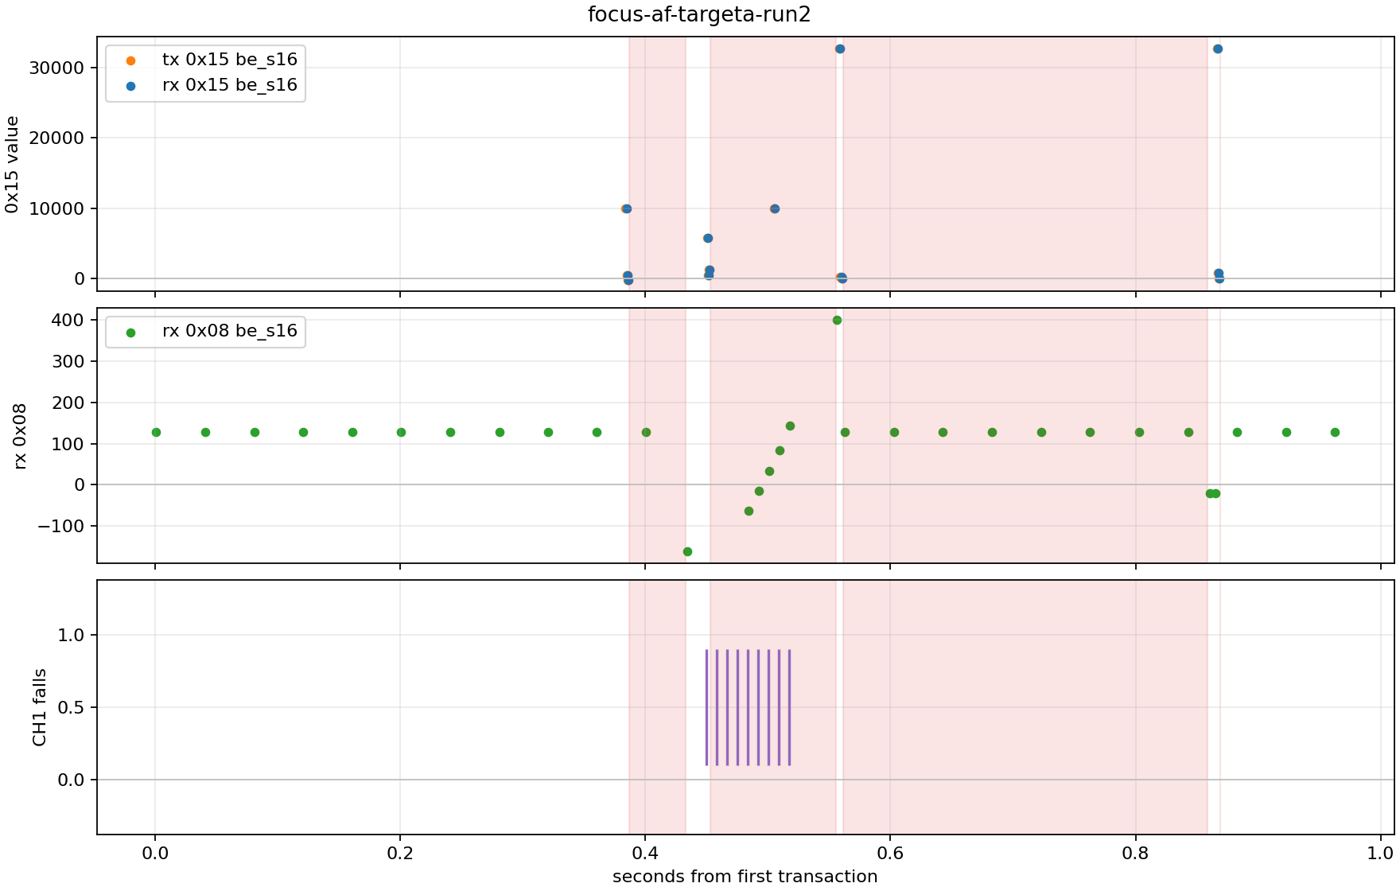
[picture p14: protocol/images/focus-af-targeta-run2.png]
focus-af-targeta-run2


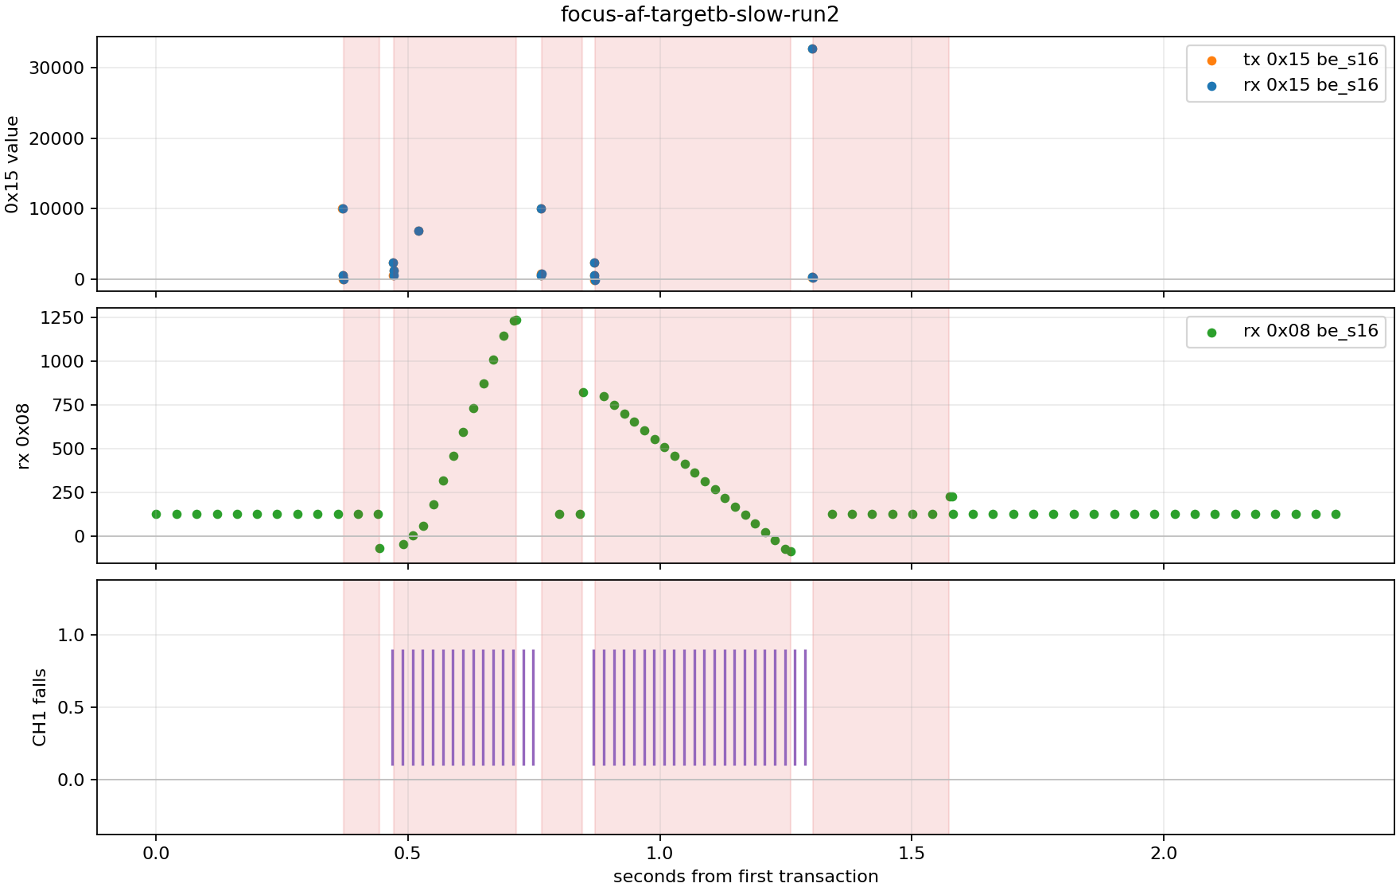
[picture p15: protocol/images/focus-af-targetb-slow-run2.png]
focus-af-targetb-slow-run2


Given the focus occasionally runs at different speeds and we see some easing in the feedback position shape, I did a review pass looking for variations to understand what the likely meaning of the first and second payloads represent. 

> Firmware string extraction found `FOCUS VLT`, `FOCUS PLS`, `FOCUS SPD` modes, which helped narrow down the 'not position' fields

### Envelope/Budget

The value doesn't seem to correlate to previous positions or the upcoming position.

There is a good linear correlation to the duration of the focus move for the smaller values, ~0.141ms/count. The 5000 value move is less correlated though and the 32767 doesn't align with motor actuation.

> Treat this as poorly substantiated correlation

| Tag 0 packet  | Value | Mean CH2 low |
| --- | --- | --- |
| `01 f4 15 18` | `500` | ~16.6 ms |
| `02 38 15 1e` | `568` | ~31.4 ms |
| `02 87 15 10` | `647` | ~39.3 ms |
| `02 e2 15 0e` | `738` | ~51.4 ms |
| `13 88 15 3e` | `5000`  | ~250.6 ms |
| `7f ff 15 10` | `32767` | - |

### Speed/Mode

The 'tag 1' field isn't fully understood. In the slower AF captures (low light) there are fewer and longer CH2 pulses which provide the most with variation. 

- Manual focus tests all have `01 20 15 40`, the constantly seen `288` value in the longer captures. 
  - Anecdotally the focus speed/sound is the same in manual mode?
- Autofocus runs show different values:
  - GF45 and GF110 captures have the some of the same fields 

This might also relate to the focus move type or curve?

| `0x15` with Tag 1 payloads (hex) | BE16 decimal |
| --- | --- |
| `01 20` | `288` |
| `01 21` | `289` |
| `01 23` | `291` |
| `02 00` | `512` |
| `02 01` | `513` |
| `02 03` | `515` |
| `03 21` | `801` |

### Target Position

Like the focus ring, the `ss ss` appears to be a **signed big-endian 16-bit position value** that makes sense. These packets are `tag 2` i.e. the final byte bits 6..7 are `11` .

On the GF45mm:

```
ff d9 15 8c -> -39    near infinity?
ff f2 15 86 -> -14
00 0a 15 a2 -> 10
02 4c 15 b6 -> 588
04 a2 15 9e -> 1186
04 d3 15 b0 -> 1235   close focus
```

The magnitude of the value sent seems to correlate to the low-pulse duration which probably represents an absolute focus target.

Also has high correlation (deltas of mostly 0, `gf45_slow_af` has 2-count difference) to the feedback value.

### Position Feedback

A feedback signal from the lens in `0x08` messages follows the BE16 format, i.e.  `rx ss ss 08 cc`. These all have tag = 1.

The feedback value is sometimes `32767` which is `2^15 - 1` and would probably be the end of the encoder's range. If that value is seen we'd treat it as a sentinel/health update but probably not a valid position.

The focus feedback values don't seem valid outside of active focus actuation regions.

### Resolution Differences

The GF110mm has a nicer ultrasonic or linear motor, and there seems to be much finer focus control available. This is backed up by focus sweep captures showing ~17x larger span of values:

| Lens  | Motor command | Width | Resolution | Feedback range | Width | Resolution |
| ----- | --- | --- | --- | --- | --- | --- |
| GF110 | -927 .. 22638 | 23565 counts | ~14.5 bits | -845 .. 22638  | 23483 counts | ~14.5 bits |
| GF45  | -163 .. 1235  | 1398 counts  | ~10.5 bits | -162 .. 1235 | 1397 counts  | ~10.5 bits |

The faster response of GF110 focus is also demonstrated

| Capture Group | GF110 mean CH2 low | GF45 mean CH2 low |
| --- | --- | --- |
| Manual focus throw | ~6.0 ms | ~24.9 ms |
| Normal AF | ~39.2 ms | ~147.9 ms |
| Dark/slow AF | ~44.4 ms | ~229.0 ms |

## Focus Mode?

The `0x2a` packets (acked as `0xaa`) are one of the only unique packets with strong correlation to the focus mode selection switch on the GFX50R. 

It appears once in each of the single AF-S/AF-C/MF change captures for both GF45 and GF110, and repeats four times in the AF-S/AF-C/MF back and forth capture. It's also seen in wake, power-on and a few AF captures which would be expected.

The payload doesn't seem to change predictably between modes, `00 04 2a 72` is in each capture.

```
00 02 2a 2e    upper2 = 0, power-on, lens-mount, preview-exit, and some focus-context captures
00 02 2a 70    upper2 = 1, half-shutter AFS/MF captures
```

```
00 00 2a 6e    Tag 0
00 01 2a 4e    Tag 0
00 02 2a 2e    Tag 0
00 04 2a 30    Tag 0

00 00 2a 6e    Tag 1
00 01 2a 4e    Tag 1
00 02 2a 70    Tag 1
00 04 2a 72    Tag 1

ACK packets
08 00 aa 40
0a 00 aa 50
0b 00 aa 58
```

It is followed by the same `00 00 3f c6` execute/latch sequence as focus and iris commands. Example sequence:

```
tx 00 00 2a 6e
rx -

tx 08 10 80 22
rx 08 00 aa 40

tx 00 00 3f c6
rx 00 00 2a 6e

tx 09 00 aa 48
rx 08 00 bf d8

tx -
rx 00 00 3f c6
```

## Firmware Update

There was a pending update for the GF110. I captured the process from `1.10` to `1.20`.

There are two firmware `.DAT` files for that update, both share the same header up to `0x200`.

- 230 long 2051-byte transfers
    - Each block takes ~10.94 ms to transfer.
    - After two packets, a ~145ms gap occurs presumably for writing a 4kB page.

- Some kind of 'transfer running' low edge on capture CH2 during the bursts
- New/update-specific packets, including a magic handshake `a5 5a 3c c3` / `c3 3c a5 5a`.
- Firmware transfer blocks appear to be shaped as a 2-byte block index + payload + trailing check byte.

The rx side has the next expected block index, and all zeros otherwise during the long transfers and the same `5a` final byte.

```
tx 00 00 <2048 bytes> xx
rx 00 01 <zeroes> 5a

tx 00 01 <2048 bytes> xx
rx 00 02 <zeroes> 5a
```

They terminate with a `0xffff` block.

```
tx 00 df <2048 bytes> xx
rx ff ff <zeroes> 5a

tx ff ff <2048 bytes> xx
rx ff 00 <zeroes> 5a
```

Reconstructing the transfer, removed framing:

-  `tx_long_strip2last` has a 262,144 bytes of contiguous matches against `GFUP0004.DAT` after `0x200`.
-  Sparse chunks cover 302,613 bytes, 58% of `GFUP0004.DAT` after the `0x200` header.
-  `GFUP0019.DAT` doesn't align as well, estimated 20.6% match. Could be a separate firmware bundle for a manufacturing variant?

Before the first transfer, the sequence looks like this:

```
tx 80 20 28 24
rx 00 00 00 00

tx 08 10 80 22
rx 08 02 80 14

tx a5 5a 3c c3	magic word?
rx c3 3c a5 5a	magic variant?

tx 80 20 28 24
rx a5 5a 3c c3	ack magic

tx 08 10 80 22
rx 08 00 a8 36

tx 00 00 00 00
rx 80 20 28 24

tx 08 00 a8 36
rx 08 00 80 12
```

Another sequence:

```
tx d8 e0 06 34
rx 00 00 00 00

tx 09 10 80 2a
rx 08 00 86 2a

tx 00 00 32 0e
rx d8 e0 06 34

tx 0a 00 86 3a
rx 09 00 b2 28

tx d0 00 32 44
rx 00 00 32 0e

tx 0b 00 b2 38
rx 0a 00 b2 72

tx 00 00 00 00
rx d0 00 32 44

tx 08 00 b2 62
rx 0b 00 80 2a
```

Small packets:

| Dir | Packet | Msg | Examples |
| --- | --- | --- | --- |
| `rx` | `08 00 86 2a` | `0x06` | `8 241` |
| `rx` | `d8 04 06 12` | `0x06` | `242` |
| `rx` | `d8 e0 06 34` | `0x06` | `9` |
| `rx` | `c3 3c a5 5a` | `0x25` | `2` |
| `rx` | `08 00 a8 36` | `0x28` | `4` |
| `rx` | `80 20 28 24` | `0x28` | `5` |
| `rx` | `00 00 32 0e` | `0x32` | `11` |
| `rx` | `00 07 32 34` | `0x32` | `244` |
| `rx` | `09 00 b2 28` | `0x32` | `10` |
| `rx` | `0a 00 b2 72` | `0x32` | `12` |
| `rx` | `0c 00 b2 00` | `0x32` | `243` |
| `rx` | `0d 00 b2 4a` | `0x32` | `245` |
| `rx` | `d0 00 32 44` | `0x32` | `13 246` |
| `rx` | `a5 5a 3c c3` | `0x3c` | `3` |
| `tx` | `0a 00 86 3a` | `0x06` | `10` |

An example slice of larger transfers:

| Transaction | Bytes | TX | RX | Gap (us) | TX prefix | RX prefix |
| ---: | ---: | --- | --- | ---: | --- | --- |
| 15 | 2051 | `0000 .. c8` | `0001 .. 5a` | 105632.36 | `00 00 0a 00 00 56 01 ac 02 02 04 58 05 ad 06 03 08 59 09 af 0a be 0a f0 0a 00 03 c4 09 f4 01 01 ...` | `00 01 00 00 00 00 00 00 00 00 00 00 00 00 00 00 00 00 00 00 00 00 00 00 00 00 00 00 00 00 00 00` ... |
| 16 | 2051 | `0001 .. 29` | `0002 .. 5a` | 3057.63 | `00 01 00 00 00 00 00 00 00 00 00 00 00 00 00 00 00 00 00 00 00 00 00 00 00 00 00 00 00 00 00 00 ...` | `00 02 00 00 00 00 00 00 00 00 00 00 00 00 00 00 00 00 00 00 00 00 00 00 00 00 00 00 00 00 00 00 ...` |
| 17 | 2051 | `0002 .. 69` | `0003 .. 5a` | 144296.64 | `00 02 ff ff ff ff ff ff ff ff ff ff ff ff ff ff ff ff ff ff ff ff ff ff ff ff ff ff ff ff ff ff ...` | `00 03 00 00 00 00 00 00 00 00 00 00 00 00 00 00 00 00 00 00 00 00 00 00 00 00 00 00 00 00 00 00` ... |

## Unknown Commands

Filtering and sorting for packet variatns which are less understood. Over time these should be removed from the table into their own sections.

### `0x05`

Appears with `0x06` near the start of power-up, exit-playback, and the annotated sequence

```
tx 00 00 05 14
rx 09 00 85 2e 

rx 00 00 05 14 
tx 08 00 85 26
```

GF110 captures have `00 00 05 xx` zero-payload packets across `upper2 = 0/1/2`.

### `0x06`

Fixed payload `b8 01`, echoed and ACKed before the `0x05` exchange

```
tx b8 01 06 26
rx 08 00 86 2a

rx b8 01 06 26
tx 0a 00 86 3a
```

### `0x07`

Found in the GF45mm capture of 'startup into firmware update mode'.

> TODO review that capture

### `0x09`

Appears to splits into two families by upper2 tag state. Upper 2=0 is noted in the status packet section

Some newer captures contain `upper2 = 0`. Appears in power transitions, half-shutter captures, preview/playback transitions, focus-mode-context captures, and lens mount state captures

```
tx 00 01 09 04
rx 00 00 09 24
```

```
08 00 89 36
09 00 89 3e
0a 00 89 06
0b 00 89 0e
0c 00 89 16
0d 00 89 1e
0e 00 89 26
0f 00 89 2e
```

### `0x0f`

| Count | Dir  | Msg  | ACK | Upper2 | Reason | Lenses | Captures | Top packets |
| ----: | ---- | ---- | --- | -----: | --- | --- | ---: | --- |
|  2796 | `rx` | `0f` | `True`  | 3 | undecoded | GF110,GF45 | 72 | `08 00 8f d2`, `09 00 8f da`, `0d 00 8f fa`, `0b 00 8f ea` |
|  2796 | `rx` | `0f` | `False` | 3 | undecoded | GF110,GF45 | 72 | `00 00 0f c0` |
|  2796 | `tx` | `0f` | `False` | 3 | undecoded | GF110,GF45 | 72 | `00 00 0f c0` |
|  2796 | `tx` | `0f` | `True`  | 3 | undecoded | GF110,GF45 | 72 | `08 00 8f d2`, `09 00 8f da`, `0e 00 8f c2`, `0b 00 8f ea` |

### `0x10`

Appears after `0x28`, then is latched with `0x3f`

```
tx 00 01 10 22
rx 00 01 10 22
rx 0f 00 90 0c
tx 09 00 90 1c
rx 0d 00 90 3c
tx 0f 00 90 0c
rx 08 00 90 14
tx 0a 00 90 24
```

### `0x16`

Very rare command seen only in auto-focus captures so far.

Observed as `00 00 16 1a`, upper2 = 0, followed by execute/latch `00 00 3f c6` .

```
0x16 command: 00 00 16 1a
0x16 ACK:     08 00 96 2c
              0f 00 96 24
              0c 00 96 0c
```

In sequence:

```
tx 00 00 16 1a       body sends 0x16 command
rx 00 00 00 00

tx n 10 80 ??        normal tagged status/idle-ish traffic continues
rx 08 00 96 2c       lens ACK of the 0x16 command

tx 00 00 3f c6       execute/latch
rx 00 00 16 1a       lens echoes the 0x16 command

tx n 00 96 ??        body ACK/status for the 0x16 family
rx n 00 bf ??        lens ACK/status for the execute command

tx 00 00 00 00
rx 00 00 3f c6       lens echoes execute/latch

tx 08 00 bf d8       body ACK/status for execute/latch
rx n 00 80 ??        normal tagged status response

```

> TODO: Investigate and capture more examples
>
> Possible explanations (very speculative), focus-settle, AF state transition, motor-control mode boundary.
>
> Look into AF-S vs AF-C behaviour
>
> Look into the 'optics valid' drive that the GF110 runs when it's on, can be heard adjusting to gravity/orientation etc.

### `0x20`

Found in startup/shutdown/playback transitions. Likely candidate is OIS.

```
tx 00 00 20 04
rx 08 00 a0 16
rx 00 00 20 04
tx 0b 00 a0 2e
tx 0e 00 a0 06
tx 0c 00 a0 36
tx 0d 00 a0 3e
tx 0f 00 a0 0e
```

### `0x25`

Found during update process.

### `0x28`

Latched/ACKed around transition sequences, sometimes immediately before `0x15` focus events.

```
rx 08 00 a8 36
tx 80 02 28 06
rx 80 02 28 06
tx 0d 00 a8 1e
tx 80 01 28 24
rx 80 01 28 24
tx 80 04 28 4a
rx 08 00 a8 78
rx 80 04 28 4a
tx 0a 00 a8 48
tx 08 00 a8 36
tx 0e 00 a8 26
```

### `0x32`

Seen during firmware update process

### `0x3c`

Seen during firmware update capture

# Untestable Fields

## Zoom Feedback

Both of my GF lenses are primes, but there must be a field(s) which provide feedback on zoom position or focal length so the correct exif data can be written when using those lenses.

> It would be much appreciated if anyone is able to capture short, clean sequences before and after a manual change to the zoom, with and/or without taking a photo in between. Including either the photos or a copy of the exif of photos taken during the capture may allow for additional correlation

TODO: look at clonejo x-mount captures

## Image Stabilisation

Neither of my lenses have IS, but I'd likely expect a field between the camera/lens that either enables/disables it, or potentially streams other information.

Enable/disable switch state is likely sent over the protocol, and activation/status for a given photo is visible in EXIF at least.

> I'd appreciate if anyone is able to capture short, clean sequences before and after enabling the IS through a camera action. If possible, additional captures with no, some single bumps, and larger oscillating behaviour in a single axis of rotation may also help. 

Firmware analysis on IS enabled GF lenses has an `imgstabi` module with 6 fields.

```
imgstabi

手ブレスルー画開始
  camera-shake / through-image start

手ブレ補正S1AE開始 / 終了
  shake correction S1AE start / end

手ブレ補正S1AF開始 / 終了
  shake correction S1AF start / end

手ブレ補正S1LOCK開始 / 終了
  shake correction S1LOCK start / end

手ブレ補正S2露光開始 / 終了
  shake correction S2 exposure start / end

手ブレ補正S2動画開始 / 終了
  shake correction S2 movie start / end
```

Digging through the clonejo captures, `0x20` is well enough labelled for correlation.

\- Seen in `ois-on-off`, `ois-turn-on`, `ois-turn-off`, and some `on-expose-off` captures.

\- Common forms: `00 00 20 04`, `00 01 20 24`, `08 00 a0 16`.

## Teleconverter

I've seen examples/discussion online of the EXIF metadata being correctly displayed when a teleconverter is used, i.e. GF 250mm f4 reads as 350mm f5.6, along with mentions that the depth-of-field scale is correct.

This means the teleconverters are active. Electrically I'd expect it to be implemented in a daisy-chain architecture, and either the body/lens is aware of this during startup, additional packets are added in either/both directions, or it modifies packets in flight.

> If you have access to a teleconverter, I'd love to see captures with and without the TC attached for a given lens, with the iris ring rotated and focus/zoom behaviours used.

Firmware analysis of GF250 somewhat matches my guess, the lens knows the model number and identification strings for the teleconverter.

## Tilt & Shift Feedback

From some searches online, it appears that rotation and shift values are available in EXIF, it's unclear if tilt fields contain usable data? According to Fuji's GF 30mm page, 

> "For every image made with GF30mmF5.6 T/S, a built-in sensor detects and records the amount of shift and rotation dialled in"

We'd expect to see the value(s) communicated over this protocol to the body for saving in the EXIF data

> If you're fortunate enough to have access to TS lenses, I'd appreciate a series of logic captures which cover small increments in a single axis, ideally labelled with the starting and ending positions. If photos for each capture or extracted EXIF can be included that may help as well. 
>
> - Shift and tilt at zero
> - Positive shift
> - Negative shift
> - Positive tilt
> - Negative tilt
> - Rotation?

## Power Zoom

The cinema focused 'GF32-90mm t3.5 PZ OIS' has geared rings for focus/zoom/iris as well as selection switches for focus, zoom, and OIS enable. There's a rocker on the lens for controlling the power-zoom.

The switches are likely communicated to the body. The power-zoom rocker value and/or setpoint are likely communicated to the lens. I'd expect this lens to use a similar protocol, but there's a chance its rather different due to cinema-leaning market.

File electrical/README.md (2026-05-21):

# GF Mount Electrical Notes

[`springboard`](./springboard) contains PCB design files for a pogo-pin based breakout used to electrically interface with a lens.

General documentation below.

# Basics

The electrical connections between the body and lens are made with 12 spring loaded contacts (body) which mechanically align with 11 contact rectangles (lens).

## Body Side

- Spring-loaded pins are on the body side, flat pads are on the lens side.
- The spring section of the pins have a 1.0 mm diameter, and a maximum achievable travel of 0.8mm.
- The spring pins have a conical/round tip.
- The pins are gold.
- The pins are spaced 6° apart, for a total span/range of 66°. There is no pin on the vertical from the mount center-point, the outermost edge pins are aligned at +33° and -33° from the vertical datum.
- The mount (metal ring/bayonet assembly) is electrically common with the exposed metal inside the battery compartment, and `Pin 5` and `Pin 6`.

## Lens Side

- The lens-side contacts are 1.6 x 1.3 mm rectangular pads, with the long edge aligned tangentially to the circular mount.

- When looking at the back of the lens mount, the right-most pin is a 1.3 mm x 1.3 mm square contact.

- For ease of convention, I'll label this square pad as `Pin 1`, though I don't know what the official Fuji nomenclature is.

- Based on this numbering scheme, `Pin 5` and `Pin 6` are mechanically the same contact rectangle, and therefore electrically common.

- Unlike the body side mount, the lens mount/bayonet is not electrically common with `Pin 5` and `Pin 6`.

# Poking the MCEX-45G

The extension tube provides probable contacts for both sides of the mount.

Flange to flange conductivity doesn't seem to be something that's explicitly designed for, most mating surfaces on the extension tube are anodised (therefore not conductive by contact), so the electrical path is likely through the mounting screws.

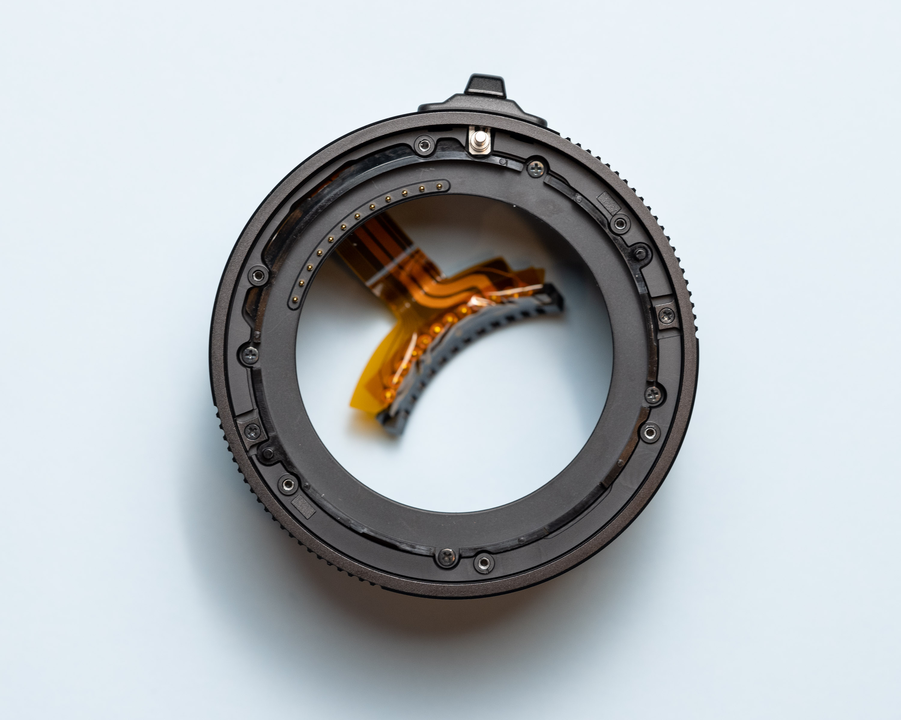
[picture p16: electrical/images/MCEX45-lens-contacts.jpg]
MCEX45-lens-contacts


The camera-side electrical connections are larger through-hole style slugs which are soldered to the flex PCB and covered with some high quality kapton tape.

The lens-side pins are more complicated. The spring contacts are actually a bespoke assembly that Fuji has designed, they don't use COTS style pogo-pins. 

- Small copper or gold (plated?) pins slide in the plastic ring.
- The flex PCB has circular exposed pads on fingers which contact the back of the gold pins. 
- An injection molded plastic retainer contains individual springs for each contact (12 in total).
- I'd recommend strongly avoiding pulling this sub-assembly apart. There are no features to retain or guide the springs, instead, the plastic retainer has 12 tiny holes presumably used with a jig during factory assembly. I had to make my own jig with needles.

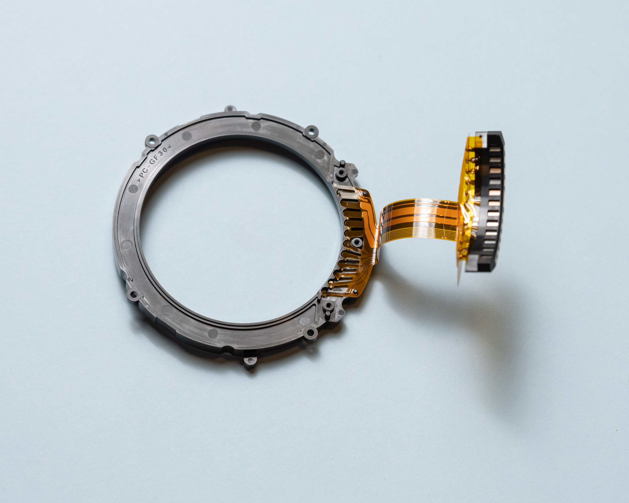
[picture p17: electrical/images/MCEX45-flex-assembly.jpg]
MCEX45-flex-assembly


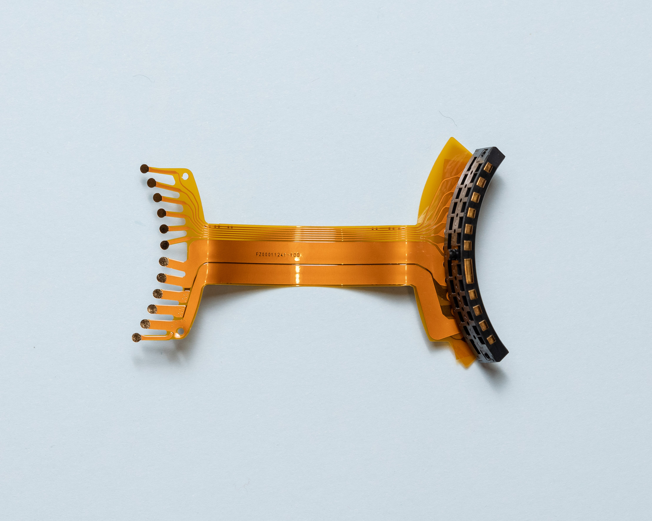
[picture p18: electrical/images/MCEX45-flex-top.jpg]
MCEX45-flex-top


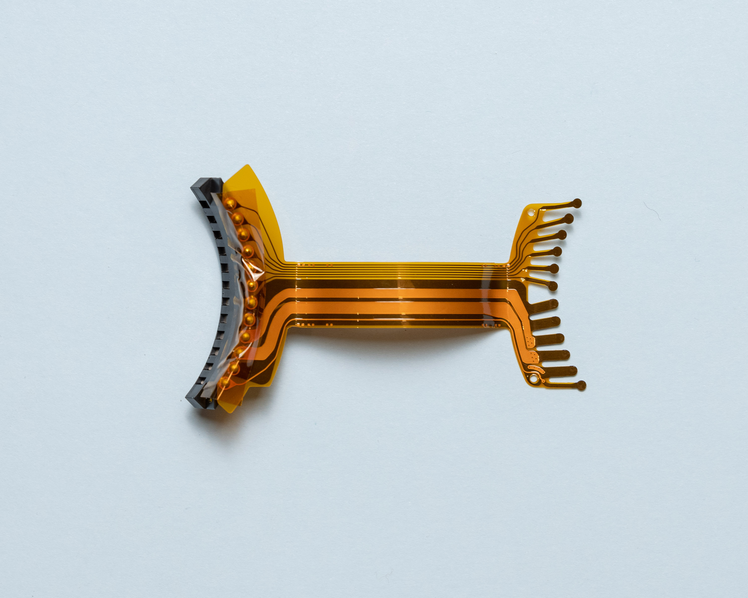
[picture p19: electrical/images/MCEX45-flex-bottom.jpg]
MCEX45-flex-bottom


After inspecting the flex PCB,  we can assume the substantially thicker traces are used on Pins 2 through 6 are used for power delivery and grounding.

- The extension tube's electrical connections are a straight 1:1 passthrough,

- therefore, the camera cannot distinguish if the tube is attached.

- Electrical connections appear to be direct connections - measurements below are subject to  measurement error.

  | Pin-Pin           | Resistance (Ω) |
  | ----------------- | -------------- |
  | Flange            | 0.14           |
  | 1 (square)        | 0.32           |
  | 2                 | 0.08           |
  | 3                 | 0.13           |
  | 4                 | 0.12           |
  | 5 (joined with 6) | 0.05           |
  | 6 (joined with 5) | 0.08           |
  | 7                 | 0.23           |
  | 8                 | 0.20           |
  | 9                 | 0.25           |
  | 10                | 0.28           |
  | 11                | 0.27           |
  | 12                | 0.29           |

The extension tube was reassembled and tested working without issue. Assembly is mostly uneventful if the lens side contact springs are left alone. The whole process took about 3-4 hours.

# Modifying the MCEX-45G for interactive instrumentation

After dissasembly (again), the external ring and internal column were taped up to avoid scratches, and marked for a drilled hole.

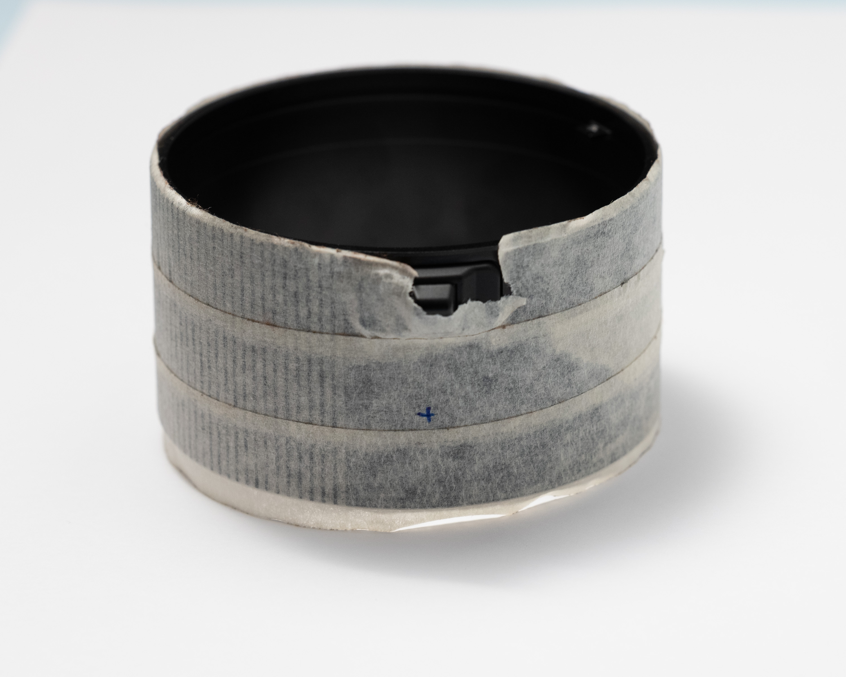
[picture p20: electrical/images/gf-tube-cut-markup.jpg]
gf-tube-cut-markup


A 1.0mm pilot hole was drilled, followed by a 4.5mm bore. This was repeated for both cylindrical pieces. The holes were then de-burred and tape removed.

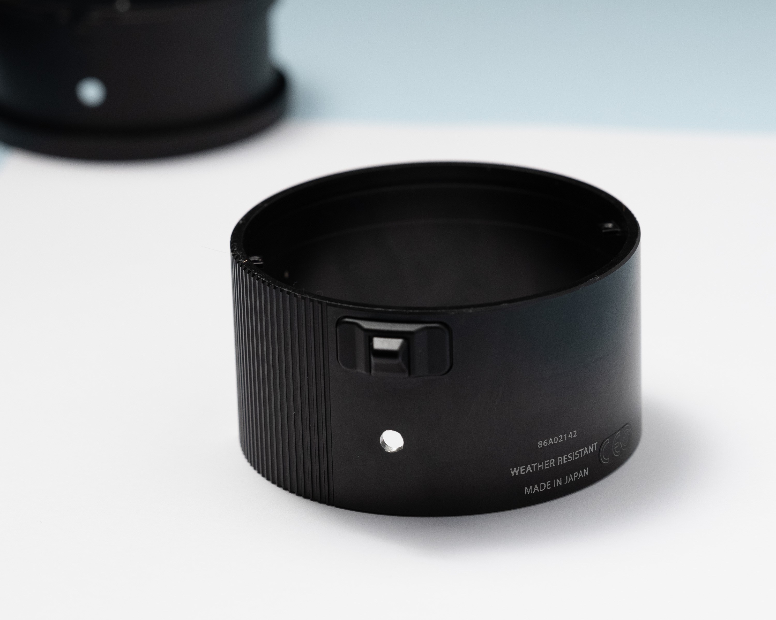
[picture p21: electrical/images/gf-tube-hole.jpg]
gf-tube-hole


The kapton tape protecting the through-hole pins from the body-side contacts was removed.

Silicone flying leads were soldered to the back of the flex.

Fresh kapton tape was applied to protect the solder joins from electrical contact with the tube/mount.

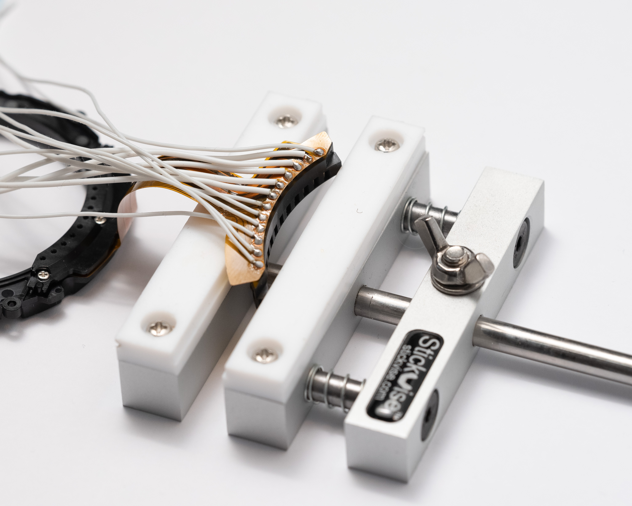
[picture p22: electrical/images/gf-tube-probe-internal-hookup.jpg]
gf-tube-probe-internal-hookup


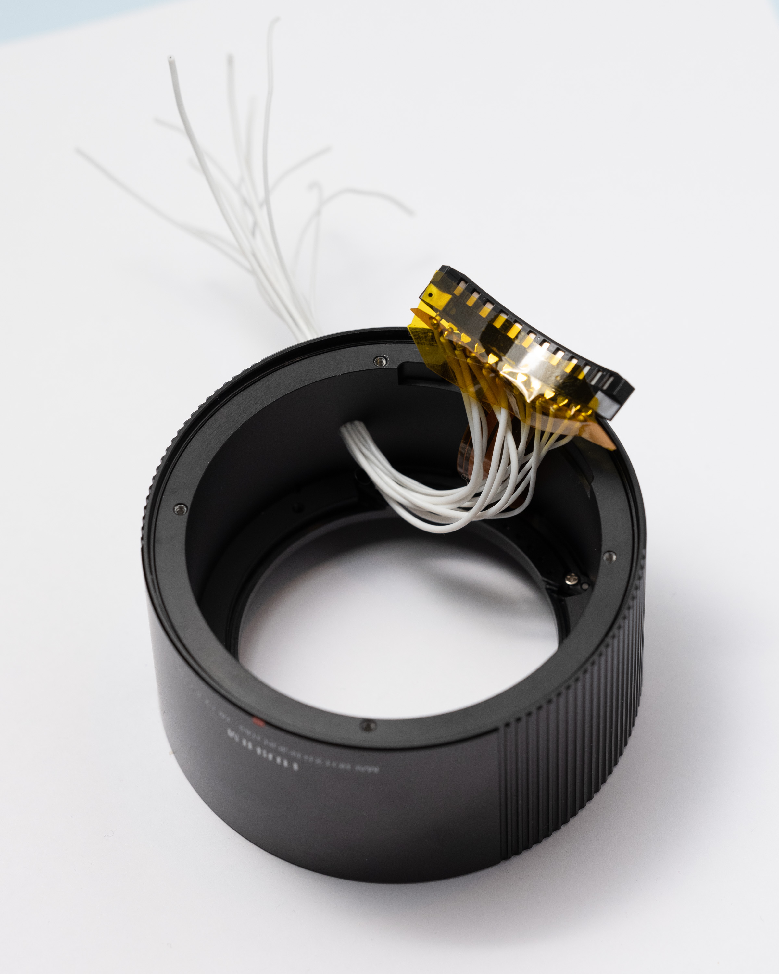
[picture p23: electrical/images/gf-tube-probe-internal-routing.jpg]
gf-tube-probe-internal-routing


After full assembly, the assembly was tested with the camera/lens to ensure no loss of operation.

The flying leads were crimped for a female 2.54mm header strip.

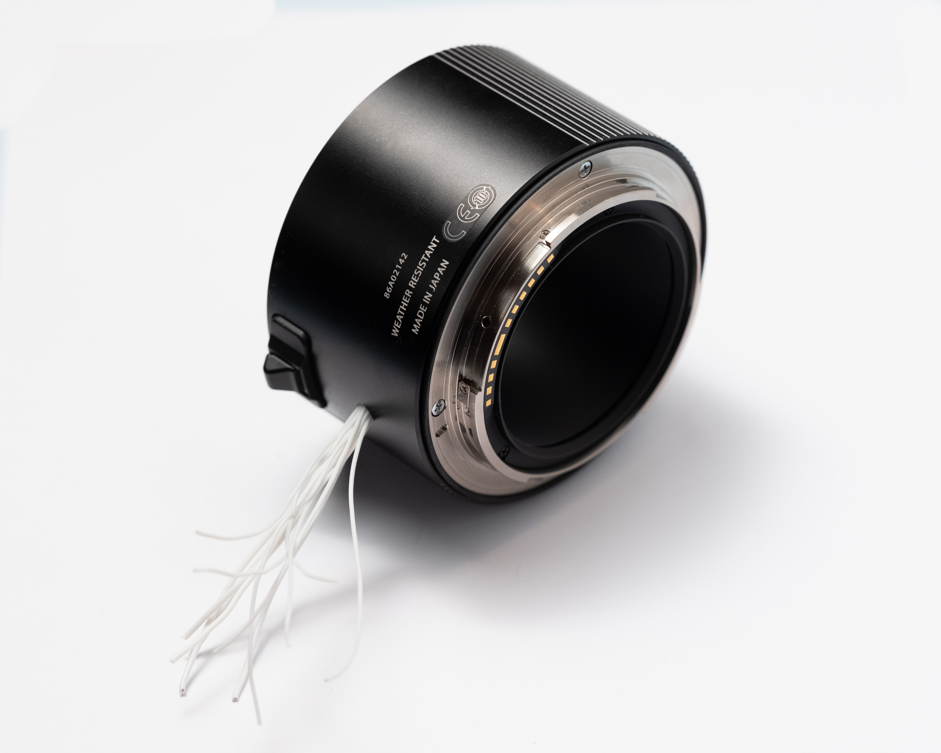
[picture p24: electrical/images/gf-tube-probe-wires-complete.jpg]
gf-tube-probe-wires-complete


This process took about 2-3 hours.

# Electrical Behaviour

Oscilloscope traces and logic-analyser capture to give context to the basic behaviour.

- All tests use the GFX50R and GF45mm with MCEX-45G.
- The camera has shutter-speed set to 1/125th, ISO 100, normally F4, 
- The camera was running from the internal battery only.
- Grounding for the scope/logic analyser is through Pins 5 and 6 respectively.

The LA capture below shows a simple sequence covering power on, focus, focus+photo, power off.

basic-behaviour

Pin names are listed in the left-hand column, and the timing markers along the top timeline have annotations matching their number/colour in the right-hand sidebar.

## Test Description

Voltage measurements taken with Keithley 2701 (front panel, 2 wire setup).

Scope set to rising/falling trigger at 100mV, 1V/div and 5ms/div.

Each pin was tested with the camera off, then turned on, autofocus engaged, then camera was turned off.

The ground was assumed to be Pin 5 based on:

- Higher current traces in MCEX-45G.
- Common with Pin 6 on lens mount side.
- Electrically common (v.low resistance to Pin 6 and GFX body-side mount).

### No lens connected

GFX 50R with MCEX-45G. No lens mounted.

| Pin  | Voltage  | Scope/Notes |
| ---- | --- | --- |
| 1 | 3.3V | Goes high when camera turned on, slow fall when camera turned off. |
| 2 | ~10mV | - |
| 3 | ~10mV | - |
| 4 | ~0.003mV | - |
| 5 | - | Used as ground connection. |
| 6 | 0mV | Electrically common to Pin 5. |
| 7 | 8mV | - |
| 8 | 8mV | - |
| 9 | 8mV | - |
| 10 | 7mV | - |
| 11 | 8mV | - |
| 12 | 15mV | - |

### GF45mm connected

GFX 50R with GF 45mm f2.8 via MCEX-45G.

| Pin  | Voltage | | Scope/Notes |
| ---- | --- | --- | --- |
| 1 | 0V | | Never triggers scope, even with varied settings.<br />Acting as (part of) lens detect? |
| 2 | 5.32V | | Just DC. |
| 3 | 6.72V | | Just DC. |
| 4 | 8.01V | | Just DC.<br />Minor ~100mV ripple when focus motor engages.  |
| 5 | - | - | Used as ground connection for scope |
| 6 | - | - | Electrically common to Pin 5 |
| 7 | 3.4V | Normally high | Infrequent squarewave behaviour.<br />No immediately recognisable pattern. |
| 8 | 3.38V | Normally high | High speed edges, infrequently triggered.<br />Pulses LOW for approx 100-350ns at a 10ms interval. |
| 9 | 0V | Normally low  | Squarewave, role unclear but probably data line. |
| 10 | 3.3V | Normally high | Squarewave, obviously a clock line at 1.5MHz.<br />Used periodically. |
| 11 | 0V | Normally low  | Squarewave, obvious data line. |
| 12 | 3.3V | Normally high | Squarewave, no discernable pattern.<br />Seems to go low when iris closes. |

## Pin 7

- Trace is captured after the camera was asked to focus on an object. 
- Logic level. Normally high.
- No obvious pattern, but is mostly likely related to AF lens motor activation.

P7-FOCUS

## Pin 10

- 1.5Mhz squarewave on Pin 10.
- Logic level. Normally high.
- Is assumed to be a SPI style clock. 

P10-IDLE

## Pin 11

- Pin 11 appears to behave like a SPI style data line. 
- Logic level. Normally low. 

P11-IDLE

## Pin 12

- Iris ring on lens is being twisted slowly by hand.
- Logic level. Normally high.
- Correlates to iris inside the lens closing. The short flickers in this trace anecdotally match the sound of the iris, and the exposure-flicker behaviour of the EVF as the camera adjusts.

P12-IRIS-TURNED

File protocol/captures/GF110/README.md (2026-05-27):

# Saleae Logic Captures

These are from one capture session with GF110mm F2 and GFX50R using extension tube for sniffing.

### Aperture Control

The GF110mm F2 control ring has third-stop increments from f2 to f22.

For iris captures, labelled using the `f4.0-f5.6.sal` style scheme as attempts to capture a full command and lens iris change:

- The camera was mostly manual, had depth-of-field preview enabled
- The camera was set to the first f-stop value in the file-name
- I changed the focus control ring one click, which results in the second f-stop in the file name
- Logic2 was configured to trim the capture around the channel4 falling edge which occus when the iris changes

> Ch4 edge duration increases as the iris change takes longer. Unsure if this is some kind of 'ready' signal or part of the autoexposure behaviour?

Additional iris captures using the scheme demonstrate larger changes, i.e. `f2.8-f16.sal`.
Also captured a reversed version of the above process, starting with depth-of-field preview enabled at a smaller f-stop, and then disabling it to open up. i.e. `f8.0-f2.8.sal`.

A pair of *dof-preview enabled* longer runs from one end to the other are included in `iris-sweep-f2.0-to-f22.sal` and `iris-sweep-f22-to-f2.0.sal`. These generally seem to have corresponding negative pulses on CH4 when the iris changes physically. 

For just the command ring *without dof preview* enabled there is no triggerable edge. A single capture `iris-ring-sweep-f2.0-to-f22.sal` starts at f2.0, and I increment the ring gradually until f22. A reversed version `iris-ring-sweep-f22-to-f2.0.sal` is also provided.

> It was a little unclear in some tests if the camera was changing iris value immediately after a ring rotation, sometimes it would wait and I think the viewfinder brightness adjustment was easing between steps?

The lenses also have a `A` for auto-aperture, and `C` for custom setting where the body wheel can be used to set it. I included captures of these. There is no dof preview available in `A` mode. Auto picked f2, and the custom value was f4, so iris actuation and ring settings will be in the same capture.  

Additional captures in custom mode using the body shutter control ring with dof-preview enabled are `custom-aperture-*`.

A capture in auto mode `auto-aperture-dark-to-bright` has the camera starting at f2 due to darker room, and I brought my phone torch in front and then away from the lens. Could hear the lens stopping down, and the f-stop indicated on the camera display changed as it tried to auto-expose. Camera was in fixed shutter-speed and fixed ISO during this test.

### Focus Control

When the camera is in autofocus mode, there is no visible change to the camera or lens when the focus ring is rotated. These captures are `focus-ring-...`, with varying distance and speeds, in both directions.

When the camera is in manual focus mode, moving the focus control ring causes motor acutuation. The logs following `focus-ring-af-*` are in that mode and have motor actuation signals on CH2.

## Focus Motor

A series of captures made in manual focus mode manually moving the ring small increments to cover the focus range, `focus-throw-from-min-to-half.sal` is small increments roughly one second apart from inf (~1m on digital scale, to 2m on scale). There's faster/continuous moves from min-to-inf and inf-to-min capture.

The `focus-ring-af-` captures also include motor drive.

Autofocus drive behaviour is in a series of captures following the scheme `focus-af-targetx-runY.sal` where X is a unique focus target that we start at and successfully focus on, and Y is the n-th repetition of the test. This is because the AF search sometimes hunts differently.

- `A` runs are on the 'longer' end of the focus scale, ~3.4m indicated, but the macro adapter is in-use so these distances aren't useful, actual target was about 30cm away. Iris was set to f3.2?
- `B` runs are in the near end of the focus scale, ~1m indicated, also with the macro adapter.
- The two runs named `focus-af-targetB-runX-dark` 1 and 2, there was less light on the target and it was done at f22 which caused it to hunt a bit more.

Additional focus hunting tests with tenscap meant it hunted and failed to focus.
- `focus-mf-lenscap.sal` is in MF mode, back-button focus used to trigger AF
- `focus-afs-lenscap.sal` in single-af mode, back-button used to trigger
- `focus-afc-lenscap.sal` in continuous servo focus, backbutton held for 3 seconds.

# Power On/Off

A series of new captures `power-onX.sal` and `power-offX.sal`. Done with lens set to "C" with the camera showing F20 (can't remember)? Camera was in MF setting.

`power-on4-f2` and off variant were done with the iris control ring set to f2.0.

The camera runs a sensor clean on shutdown.

## Preview Mode

`preview-mode-enter` and `preview-mode-exit` are variations where the lens is audibly woken up/slept but not a full camera power cycle, no sensor cleaning.

Camera was set to F2, 1/125, ISO1600, AFS and was awake/viewfinder before going into image review.

## Sleep

Camera was in viewfinder state and allowed to disable/sleep the display. I woke it by rotating the manual focus ring. 
Set to 15-seconds.

`display-sleep` and `display-wake`.

## Lens Removal

`lens-dismount` and `lens-mount` were done while the camera was on, as a variation.

## Firmware Update

Power-up while holding DISP/BACK button brings up the update menu. `power-into-fwupdate.sal`

Display reports "Body version 3.11" and "Lens version 1.10".

# Firmware Update

Turns out an update was available. We started on 1.10, updated to 1.20 dated `27-04-2023`.

`fw-update-1p20.sal` is the entire sequence.

# State Changes

Camera otherwise idle while changing the 3-position focus mode lever.

`mode-afc-to-afs`, `mode-afs-to-afc` and `mode-afc-to-mf` and `mode-mf-to-afc` are the possible individual directions.

`mode-afs-afc-mf-sweep` sweeps through them and back.

# Half-shutter

The lens was set to f2. Shutterspeed at 1/125. Iso 1600. 

- `half-shutter-mf-lenscap` for manual focus mode with lenscap
- `half-shutter-mf` for manual focus mode, no lenscap
- `half-shutter-afs-lenscap` includes focus attempt
- `half-shutter-afs` includes focus attempt

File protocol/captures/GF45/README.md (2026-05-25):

# Saleae Logic Captures

These are from several capture sessions with GF45mm f2.8 and GFX50R using extension tube for sniffing.

### Aperture Control

The GF45mm F2.8 control ring has third-stop increments from f2.8 to f32.

For iris captures, labelled using the `f4.0-f5.6.sal` style scheme as attempts to capture a full command and lens iris change:

- The camera was mostly manual, had depth-of-field preview enabled
- The camera was set to the first f-stop value in the file-name
- I changed the focus control ring one click, which results in the second f-stop in the file name
- Logic2 was configured to trim the capture around the channel4 falling edge which occus when the iris changes

> Ch4 edge duration increases as the iris change takes longer. Unsure if this is some kind of 'ready' signal or part of the autoexposure behaviour?

Additional iris captures using the scheme demonstrate larger changes, i.e. `f2.8-f16.sal`.
Also captured a reversed version of the above process, starting with depth-of-field preview enabled at a smaller f-stop, and then disabling it to open up. i.e. `f8.0-f2.8.sal`.

A pair of *dof-preview enabled* longer runs from one end to the other are included in `iris-sweep-f2.8-to-f32.sal` and `iris-sweep-f32-to-f2.8.sal`. These generally seem to have corresponding negative pulses on CH4 when the iris changes physically. 

For just the command ring *without dof preview* enabled there is no triggerable edge. A single capture `iris-ring-sweep-f2.8-to-f32.sal` starts at f2.8, and I increment the ring gradually until f32. A reversed version `iris-ring-sweep-f32-to-f2.8.sal` is also provided.

### Focus Control

When the camera is in autofocus mode, there is no visible change to the camera or lens when the focus ring is rotated. These captures are `focus-ring-...`, with varying distance and speeds, in both directions.

When the camera is in manual focus mode, moving the focus control ring causes motor acutuation. The logs following `focus-ring-af-*` are in that mode and have motor actuation signals on CH2.

## Focus Motor

A series of captures made in manual focus mode manually moving the ring small increments to cover the focus range, `focus-throw-small-spaced-moves-from-inf-to-min.sal` and a min-to-inf capture.

`focus-throw-large-alternating.sal` is a larger movement back and forth in the approx middle of the range.

Autofocus drive behaviour is in a series of captures following the scheme `focus-af-targetx-runY.sal` where X is a unique focus target that we start at and successfully focus on, and Y is the n-th repetition of the test. This is because the AF search sometimes hunts differently.

- `A` runs are on the 'long' end of the focus scale, between 10m and inf but the macro adapter is in-use so these distances aren't useful.
- `B` runs are in the approx end of the focus scale, also with the macro adapter.
- The two runs named `focus-af-targetB-slow-run` 1 and 2, there was nearly no light on the target so the autofocus had to hunt much slower to achieve a lock.

These tests were all done at wide-open f2.8 to try and keep iris change behaviour out of it.

# Power On/Off

A series of new captures `power-onX.sal` and `power-offX.sal`. Done with lens set to "2.8" Camera was in AFS setting.

The camera runs a sensor clean on shutdown.

## Preview Mode

`preview-mode-enter` and `preview-mode-exit` are variations where the lens is audibly woken up/slept but not a full camera power cycle, no sensor cleaning.

Camera was set to F2.8, 1/125, ISO1600, MF and was awake/viewfinder before going into image review.

## Sleep

Camera was in viewfinder state and allowed to disable/sleep the display. I woke it by rotating the manual focus ring. 
Set to 15-seconds.

`display-sleep` and `display-wake`.

## Lens Removal

`lens-dismount` and `lens-mount` were done while the camera was on, as a variation.

## Firmware Update

Power-up while holding DISP/BACK button brings up the update menu. `power-into-fwupdate.sal`

Display reports "Body version 3.11" and "Lens version 1.00".

# State Changes

Camera otherwise idle while changing the 3-position focus mode lever.

`mode-afc-to-afs`, `mode-afs-to-afc` and `mode-afc-to-mf` and `mode-mf-to-afc` are the possible individual directions.

`mode-afs-afc-mf-sweep` sweeps through them and back.

# Half-shutter

The lens was set to f4. Shutterspeed at 1/125. Iso 1600. 

- `half-shutter-mf-lenscap` for manual focus mode with lenscap
- `half-shutter-mf` for manual focus mode, no lenscap
- `half-shutter-afs-lenscap` includes focus attempt
- `half-shutter-afs` includes focus attempt

### Notes

`idle-13sec.sal` is captured with the same channel config as the iris/focus captures. The camera was configured in AF mode, lens was on F2. Screen was on, no user interaction before/during the capture.

Other captures are from a prior session and are annotated where relevant.

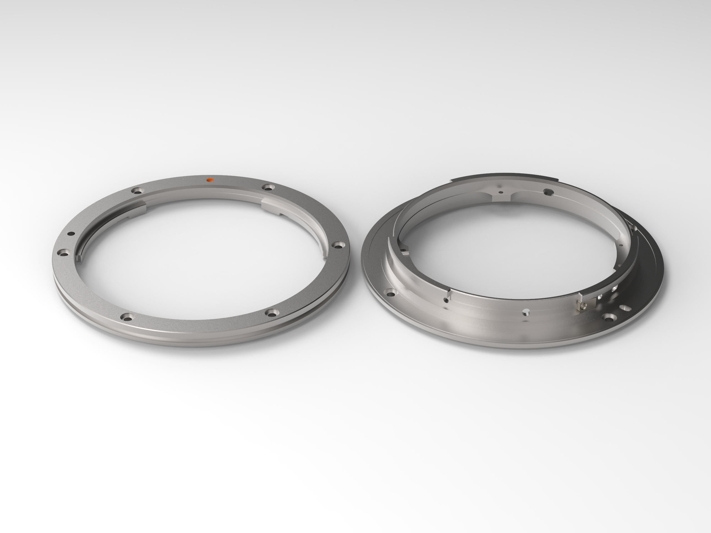
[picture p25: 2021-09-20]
mechanical/renders/angled.png

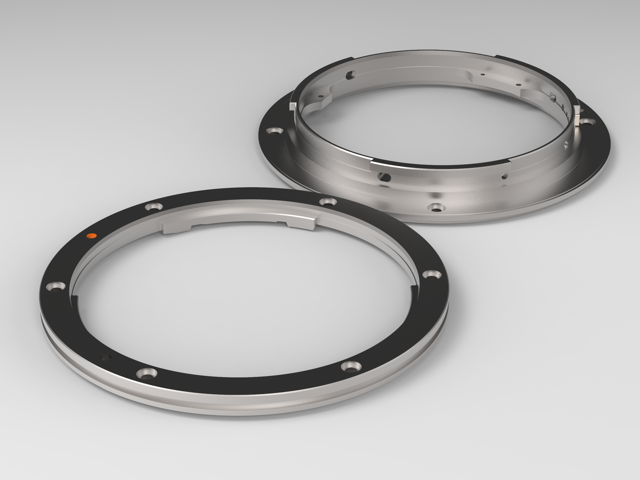
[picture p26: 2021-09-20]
mechanical/renders/detail1.png

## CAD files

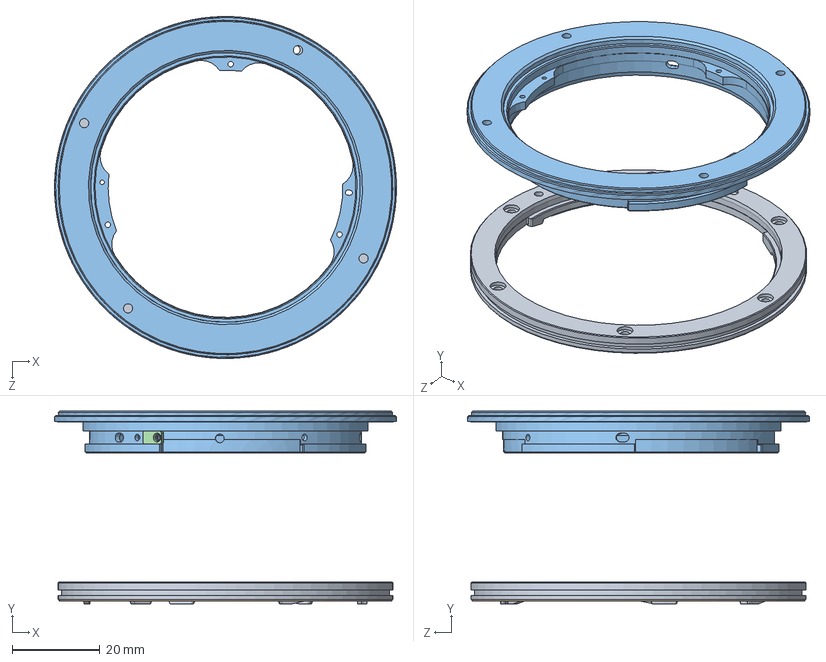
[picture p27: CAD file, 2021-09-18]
mechanical/mcad/mount-motion-test.SLDASM
78.0 x 43.9 x 78.0 mm
body-mount
body-mount-shim
lens-mount
body-mount-twist-stop

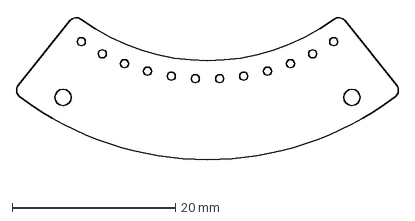
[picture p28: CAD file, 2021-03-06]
mechanical/body-spring-contacts-blank.DXF
46.8 x 20.1 mm

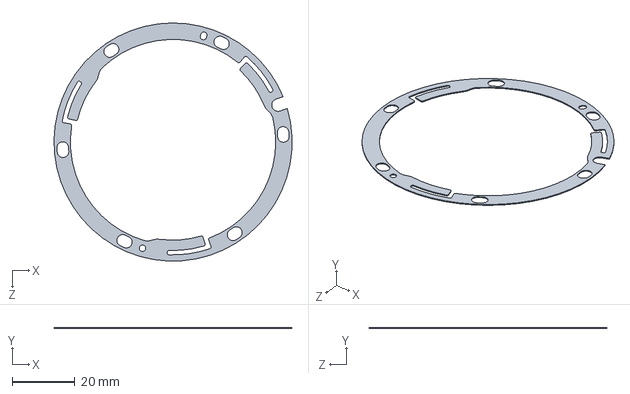
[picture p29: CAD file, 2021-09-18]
mechanical/mcad/body-mount-shim.SLDPRT
75.9 x 0.3 x 76.0 mm

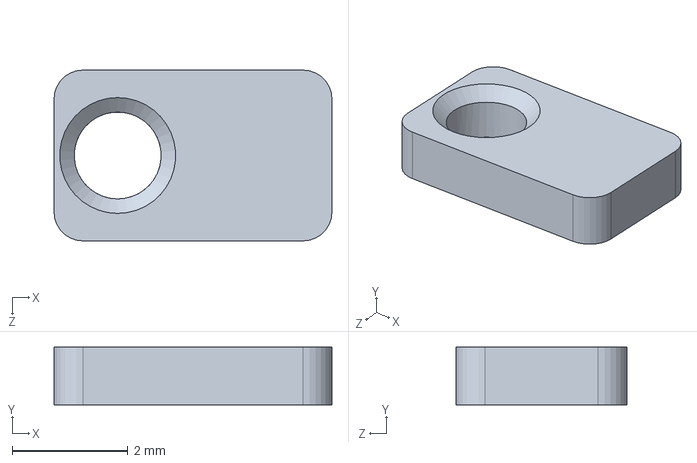
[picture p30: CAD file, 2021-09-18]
mechanical/mcad/body-mount-twist-stop.SLDPRT
4.80 x 1.00 x 2.95 mm

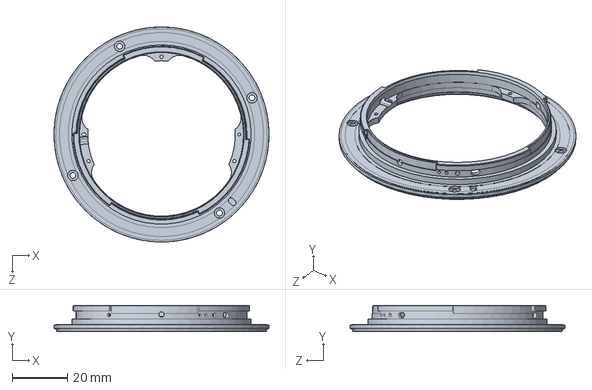
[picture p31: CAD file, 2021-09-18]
mechanical/mcad/lens-mount.SLDPRT
78.0 x 9.50 x 78.0 mm

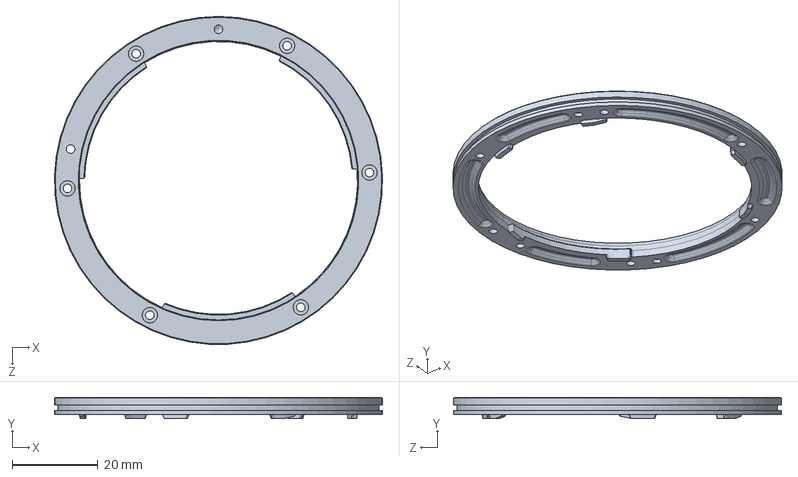
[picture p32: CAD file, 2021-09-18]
mechanical/mcad/body-mount.SLDPRT
76.5 x 4.95 x 76.5 mm

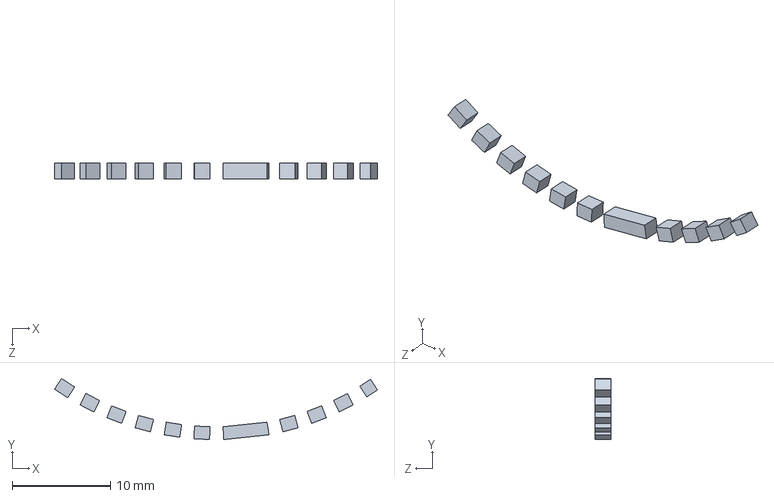
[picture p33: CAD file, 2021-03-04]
mechanical/mcad/lens-contacts-reference.SLDPRT
32.8 x 6.21 x 1.60 mm

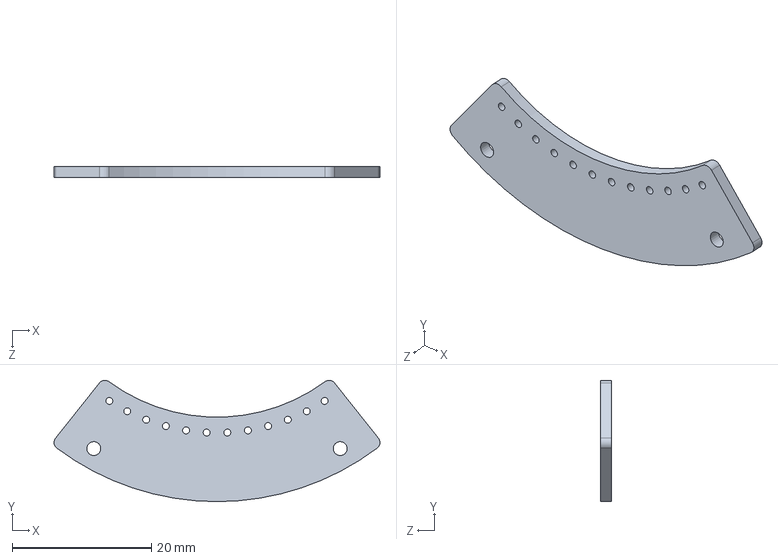
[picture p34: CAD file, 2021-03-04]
mechanical/mcad/body-spring-contacts-blank.SLDPRT
46.8 x 17.4 x 1.60 mm

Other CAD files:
mechanical/mcad/gf-lens-contacts.SLDDRW

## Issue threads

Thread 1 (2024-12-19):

Lens configuration information.

xmaowu, 2024-12-19:
Hello, may I ask if there are any methods for analyzing or understanding lens focal lengths and aperture configurations?

Scottapotamas, 2024-12-19:
There are no library features or code in this repo. What are you trying to do?

If you're reading the communication with the lens, the startup handshake describes [the lens's model as a string ](https://26oclock.com/posts/mcex-45g-teardown/#startup-identification-packets)which includes focal length and aperture.

xmaowu, 2024-12-19:
> 此存储库中没有库功能或代码。您要做什么？
>
> 如果您正在阅读与镜头的通信，则启动握手会将[镜头的型号描述为一个字符串](https://26oclock.com/posts/mcex-45g-teardown/#startup-identification-packets)，其中包括焦距和光圈。

I am reverse-engineering a Fuji X-mount lens, and I have implemented aperture adjustment and autofocus, but I don't know how to parse the model string.

Scottapotamas, 2024-12-19:
Do X-mount lenses send a similar packet during startup? If you share more details I might be able to help with the string/model parsing.

xmaowu, 2024-12-19:
The G-mount and X-mount seem to have many similarities. The lens model is within 131 bytes. Here are some data I've

example:
```
LX224A  FLSNW023XF23mmF2 R WR           {0x37, 0x43, 0x41, 0x34, 0x35, 0x38, 0x35, 0x30, }  7CA45850  {0x03, 0x85, 0x01, 0x00, 0x02, 0x50, 0x02, 0x40, 0x02, 0x50, 0x88, 0x01, }

In "LX224A  FLSNW023XF23mmF2 R WR", key data is "FLSNW023"，Other data can be modified at will.
"7CA45850" is important.
The last 12 bytes of data, with the last 10 bytes seeming to be other configuration information, should probably not be very important for now.
```

```python
    print(
        Fore.YELLOW
        + "{0:<8}".format("".join([chr(c) for c in LENS_INFO1_BUFFER[2:8]])),
        end="",
    )
    print(
        Fore.YELLOW
        + "{}".format(
            "".join([chr(c if c != 0 else 0x20) for c in LENS_INFO1_BUFFER[10:42]])
        ),
        end="",
    )
    print(
        "{"
        + "{}".format(
            "".join(["0x{:02X}, ".format(c) for c in LENS_INFO1_BUFFER[82:90]])
        )
        + "}",
        end="  ",
    )
    print(
        Fore.YELLOW + "{}".format("".join([chr(c) for c in LENS_INFO1_BUFFER[82:90]])),
        end="  ",
    )
    print(
        "{"
        + "{}".format(
            "".join(["0x{:02X}, ".format(c) for c in LENS_INFO1_BUFFER[92:104]])
        )
        + "}"
    )
```

```
LX224A  FLSNW023XF23mmF2 R WR           {0x37, 0x43, 0x41, 0x34, 0x35, 0x38, 0x35, 0x30, }  7CA45850  {0x03, 0x85, 0x01, 0x00, 0x02, 0x50, 0x02, 0x40, 0x02, 0x50, 0x88, 0x01, }
LX224A  FLSNW023XF23mmF2 R WR           {0x38, 0x41, 0x41, 0x30, 0x31, 0x32, 0x31, 0x32, }  8AA01212  {0x03, 0x85, 0x01, 0x00, 0x02, 0x50, 0x02, 0x40, 0x02, 0x50, 0x88, 0x01, }
LX209A  FLSNW009XF23mmF1.4 R            {0x37, 0x36, 0x41, 0x31, 0x30, 0x38, 0x38, 0x39, }  76A10889  {0x03, 0x41, 0x01, 0x01, 0x02, 0x30, 0x02, 0x20, 0x02, 0x30, 0xD8, 0x01, }
LX223A  FLSNW021XF35mmF2 R WR           {0x31, 0x43, 0x41, 0x30, 0x33, 0x30, 0x34, 0x30, }  1CA03040  {0x01, 0x06, 0x01, 0x01, 0x02, 0x30, 0x02, 0x20, 0x02, 0x30, 0x88, 0x01, }
LX202A  FLSNW002XF35mmF1.4 R            {0x37, 0x35, 0x41, 0x31, 0x33, 0x37, 0x35, 0x38, }  75A13758  {0x03, 0x41, 0x03, 0x11, 0x02, 0x30, 0x02, 0x20, 0x02, 0x30, 0xC0, 0x01, }
LX235A  FLSNW033XF50mmF1.0 R WR         {0x31, 0x35, 0x41, 0x30, 0x31, 0x38, 0x33, 0x32, }  15A01832  {0x01, 0x42, 0x01, 0x00, 0x02, 0x70, 0x02, 0x71, 0x02, 0x71, 0x88, 0x01, }
LX209A  FLSNW009AF 23/1.4 XF            {0x30, 0x30, 0x30, 0x30, 0x30, 0x31, 0x30, 0x31, }  00000101  {0x03, 0x31, 0x01, 0x00, 0x02, 0x30, 0x02, 0x20, 0x02, 0x30, 0xC0, 0x01, }
LX202A  FLSNW01233mmF1.4XM              {0x30, 0x30, 0x40, 0x30, 0x30, 0x32, 0x30, 0x30, }  00@00200  {0x03, 0x31, 0x01, 0x00, 0x02, 0x30, 0x02, 0x20, 0x02, 0x30, 0xC0, 0x01, }
LY039A  FLSNW002AF 56/1.7 XF            {0x39, 0x37, 0x42, 0x30, 0x30, 0x38, 0x42, 0x67, }  97B008Bg  {0x03, 0x41, 0x01, 0x02, 0x02, 0x30, 0x02, 0x20, 0x02, 0x30, 0xC2, 0x01, }
LX217A  FLSNW018  85mmF1.8              {0x30, 0x30, 0x30, 0x30, 0x30, 0x30, 0x31, 0x38, }  00000018  {0x01, 0x70, 0x01, 0x02, 0x02, 0x30, 0x02, 0x22, 0x02, 0x50, 0x8B, 0x01, }
LX374B  CLSNF074AstrHori X 27mm F2.8    {0x30, 0x32, 0x30, 0x30, 0x30, 0x39, 0x32, 0x34, }  02000924  {0x03, 0x45, 0x01, 0x02, 0x02, 0x30, 0x02, 0x21, 0x02, 0x31, 0x8A, 0x00, }
```

xmaowu, 2024-12-20:
I have found a temporary solution.
Use a lens adapter. Such as EF to X-mount, Z to X-mount. Copy data.
Under general circumstances, the parameters you want can be found.

Closed 2025-03-21.

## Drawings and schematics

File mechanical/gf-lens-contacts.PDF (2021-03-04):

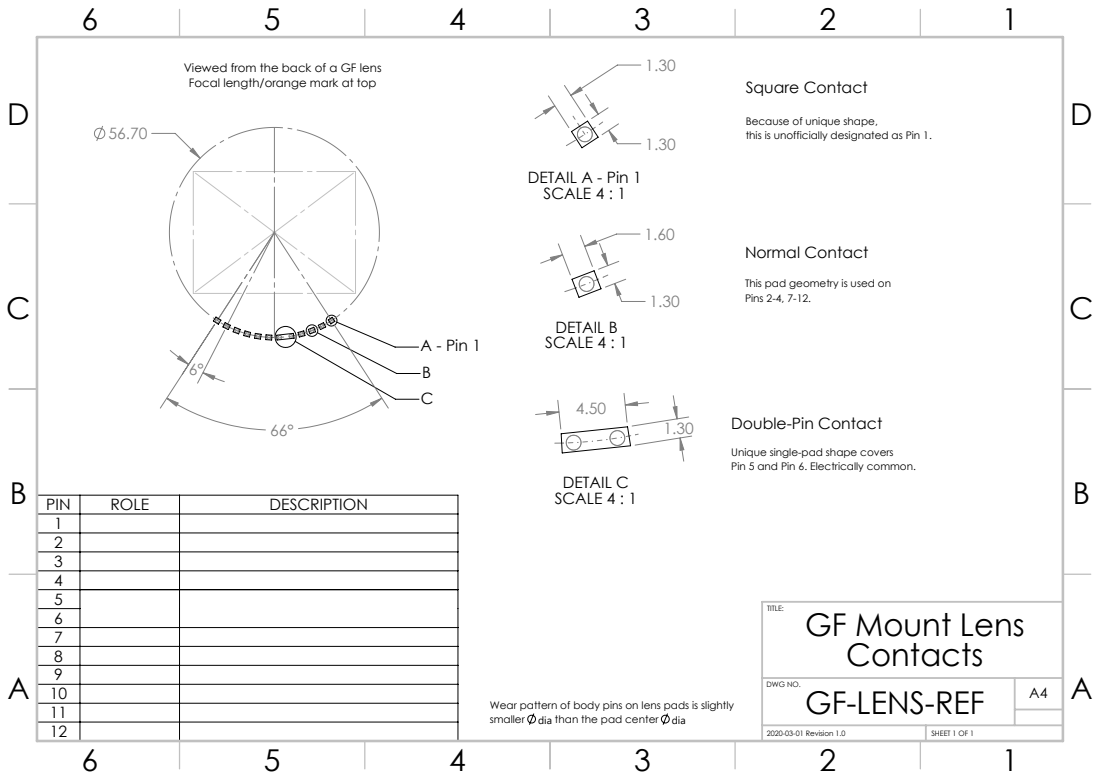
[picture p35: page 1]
A - Pin 1; DETAIL A - Pin 1 SCALE 4 : 1; DETAIL B SCALE 4 : 1; DETAIL C SCALE 4 : 1; Square Contact; Normal Contact

Viewed from the back of a GF lens
Focal length/orange mark at top

Because of unique shape,
this is unofficially designated as Pin 1.

This pad geometry is used on
Pins 2-4, 7-12.

Double-Pin Contact

Unique single-pad shape covers
Pin 5 and Pin 6. Electrically common.

PIN | ROLE | DESCRIPTION
10
11
12

GF Mount Lens
Contacts

DWG NO. | A4 GF-LENS-REF

Wear pattern of body pins on lens pads is slightly
smaller dia than the pad center dia

2020-03-01 Revision 1.0 | SHEET 1 OF 1

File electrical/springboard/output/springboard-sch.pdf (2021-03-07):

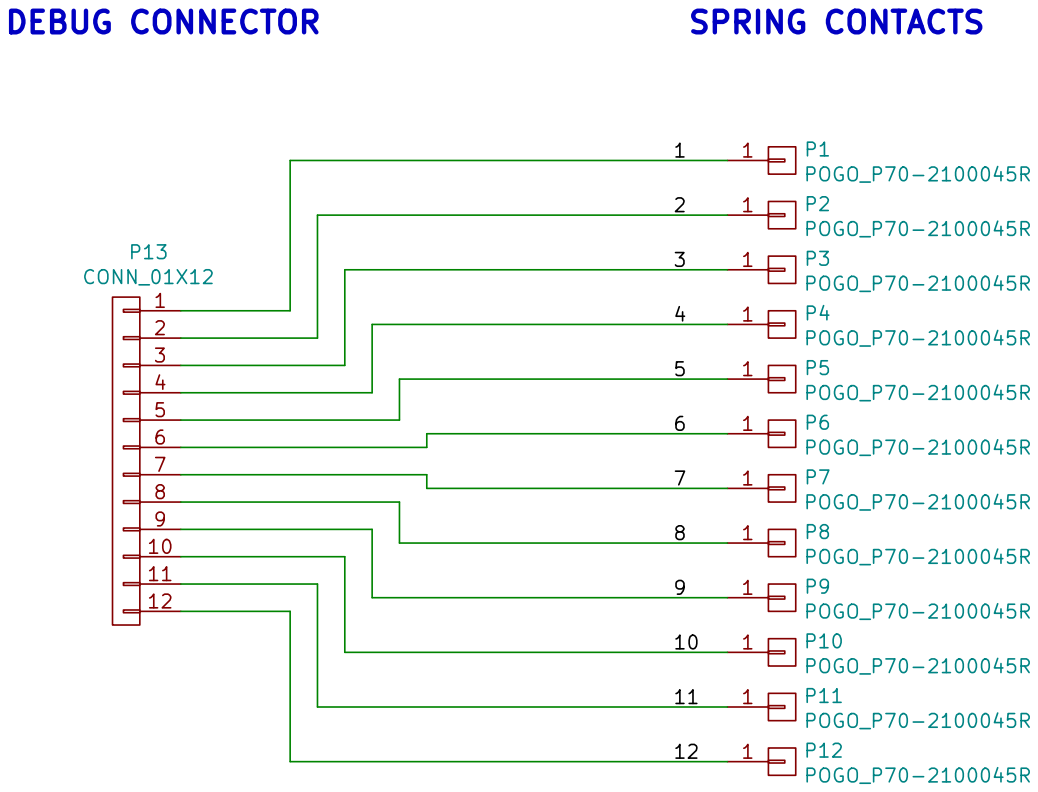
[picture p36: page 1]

10
11
12

File: springboard.sch Sheet: / Scott Rapson

Id: 1/1 Title: G Mount Body Contact Jig

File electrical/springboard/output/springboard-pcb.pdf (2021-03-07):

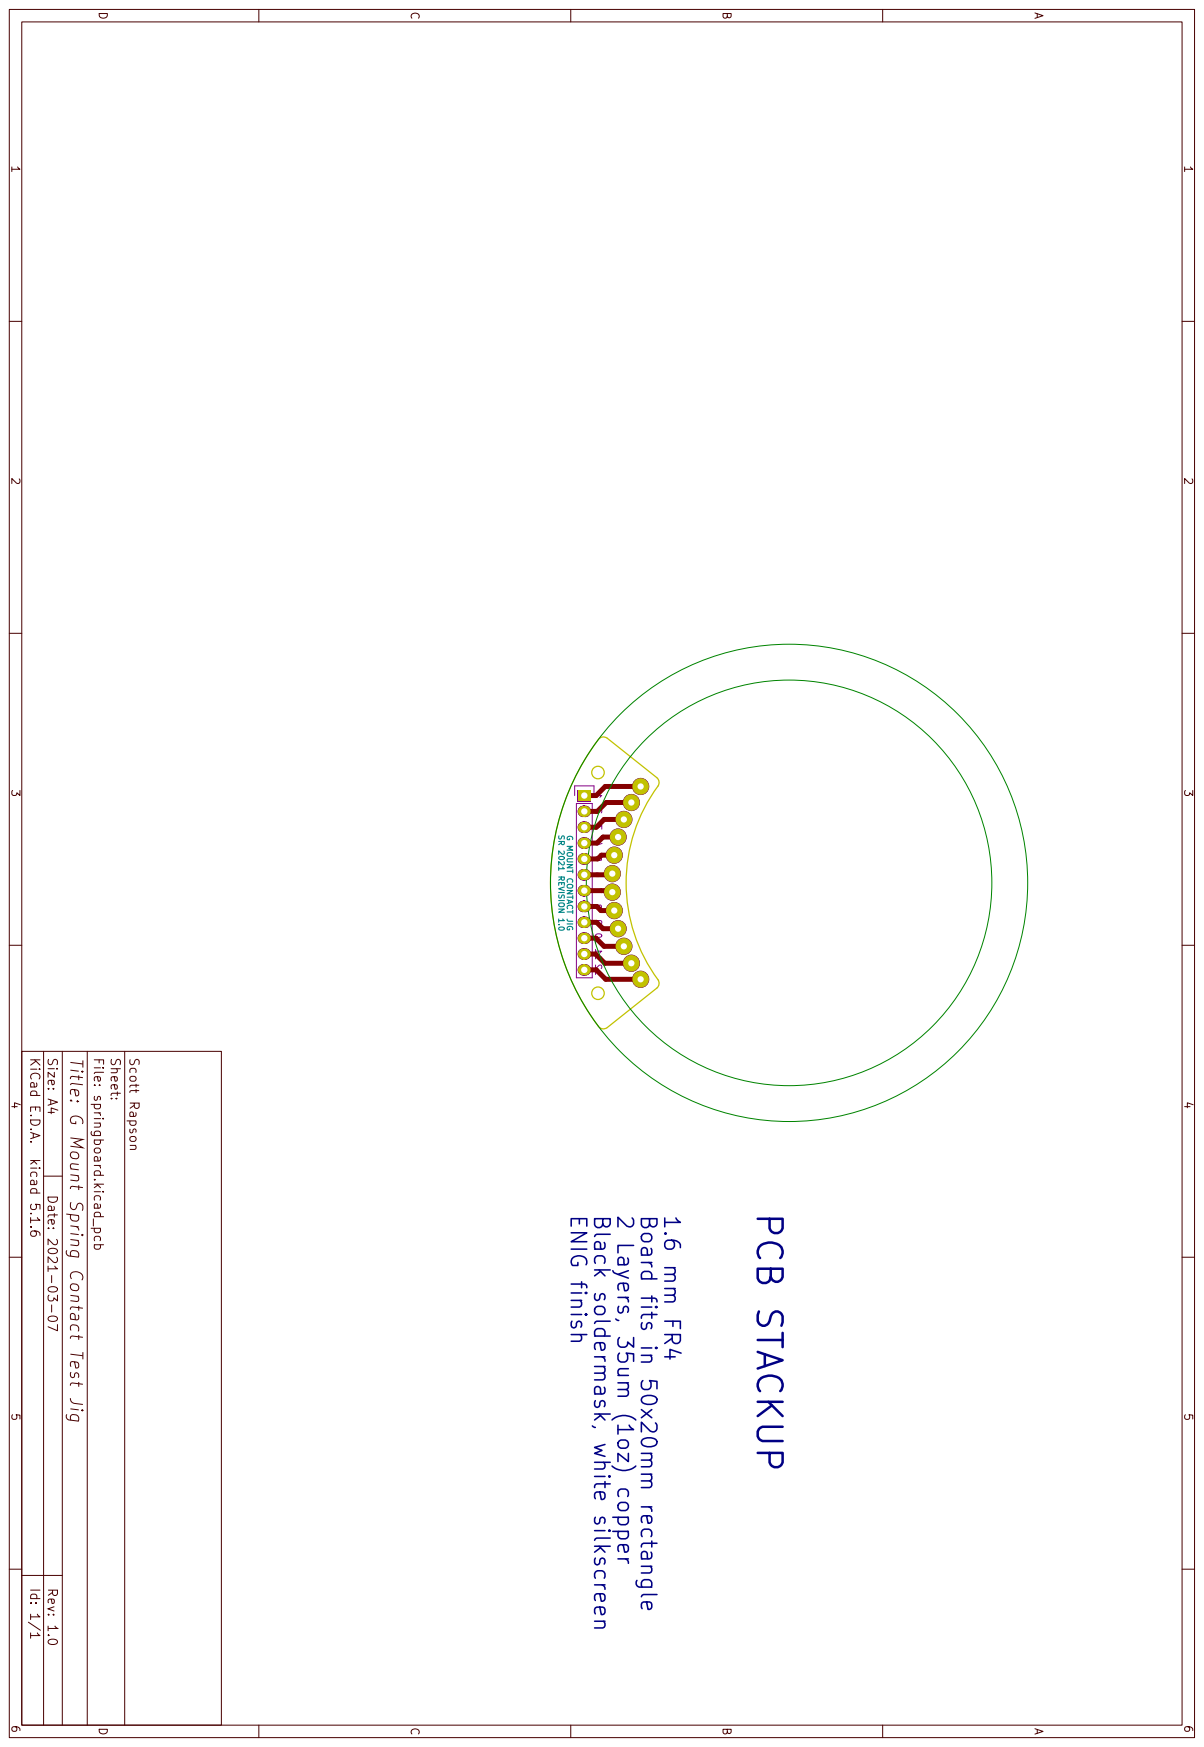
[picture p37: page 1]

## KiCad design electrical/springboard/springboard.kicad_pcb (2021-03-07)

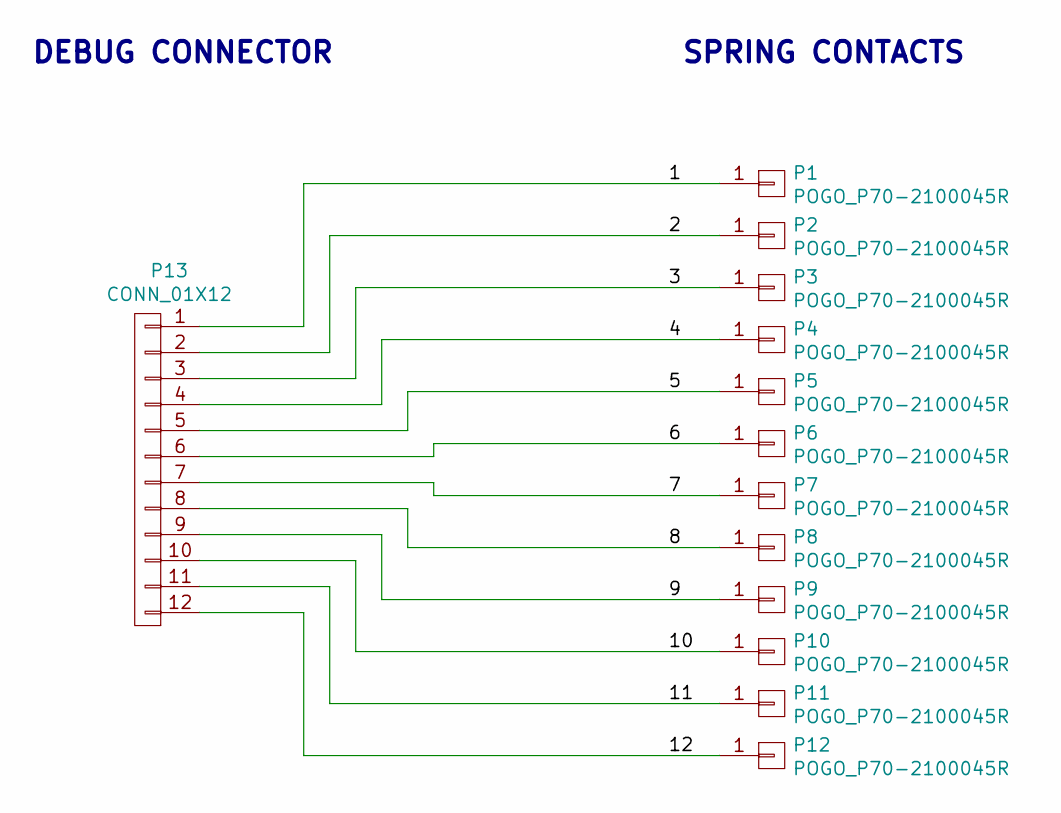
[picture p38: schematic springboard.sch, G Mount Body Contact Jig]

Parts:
P1, P2, P3, P4, P5, P6, P7, P8, P9, P10, P11, P12: POGO_P70-2100045R; HARWIN_P70-2100045R
P13: CONN_01X12; 61301211121

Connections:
/1: P1.1, P13.1
/2: P2.1, P13.2
/3: P3.1, P13.3
/4: P4.1, P13.4
/5: P5.1, P13.5
/6: P6.1, P13.6
/7: P7.1, P13.7
/8: P8.1, P13.8
/9: P9.1, P13.9
/10: P10.1, P13.10
/11: P11.1, P13.11
/12: P12.1, P13.12

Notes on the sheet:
SPRING CONTACTS
DEBUG CONNECTOR

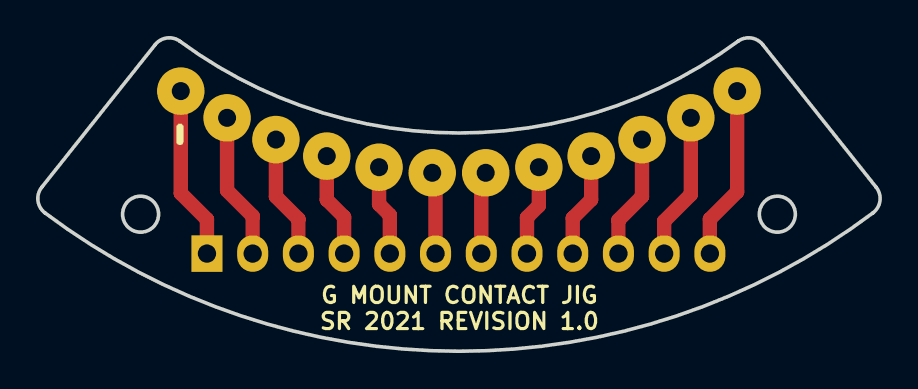
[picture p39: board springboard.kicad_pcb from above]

Board: 2 copper layers, 46.8 x 17.4 mm, 13 parts (1 on the bottom side), 12 nets.

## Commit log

2021-03-04 Started adding notes about GF mount contacts
2021-03-04 Prelim CAD reference drawings of pins and pads in GF mount
    [body-spring-contacts-blank.SLDPRT, lens-contacts-reference.SLDPRT]
2021-03-04 Prelim reference drawing for GF lens electrical contacts
    [gf-lens-contacts.SLDDRW]
2021-03-06 DXF export for pin test PCB
    [body-spring-contacts-blank.DXF]
2021-03-07 Quick PCB to mount spring-contacts matching G-mount body side
    [springboard.kicad_pcb, springboard.sch]
2021-03-07 Spring-contact PCB gerbers, renders, PDF exports
    [springboard-B_Cu.gbr, springboard-B_Mask.gbr, springboard-B_SilkS.gbr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]
2021-03-10 Note about body/lens mount metal electrical continuity
2021-08-15 Resistance measurements of GF extension tube
2021-08-21 Add basic images of MCEX-45G extension tube
2021-09-18 CAD model of lens-side of mount
    Measured carefully and validated with scans of front and back faces.
    [lens-mount.SLDPRT]
2021-09-18 CAD model of body-side of mount
    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
    [body-mount.SLDPRT]
2021-09-18 Added lens mount rotation stop 'square' piece
    Prevents lens barrel from rotating past the lock position
    [body-mount-twist-stop.SLDPRT, lens-mount.SLDPRT]
2021-09-18 Added body-mount spring shim part
    Provides preload against lens mount
    [body-mount-shim.SLDPRT]
2021-09-18 Physics based motion test of mount/unmount lens from body piece
    Tolerances seem to be ok, clearance tests pass
    [mount-motion-test.SLDASM]
2021-09-20 Electrical notes with images of tube modification and trace captures
2021-09-20 Improvements to electrical and MCEX tube modification
    Added images and descriptions of teardown for context.
2021-09-20 Add SPI notes and some preliminary packet analysis
    Lens identification and body identification packets identified.
2021-09-20 Adds renders of body and lens mount flanges
2021-09-21 Started mechanical README, folder reorganisation.
    [body-mount-shim.SLDPRT, body-mount-twist-stop.SLDPRT, body-mount.SLDPRT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]
2021-09-27 Added lens/body identification packets to checksum unit tests
2026-05-21 Findings on lens control ring packets, 'actuate iris' command
2026-05-22 Focus motor packet captures
2026-05-22 Focus motor command/feedback analysis notes/plots
2026-05-25 Protocol notes, stubs for OIS/zoom/teleconverter/shift-rotation sensor
2026-05-25 Add novel commands found in older GF captures Should have included power up/down and more focus behaviours in the recent series of captures...
2026-05-26 Remove old CRC unit test stubs, protocol notes updates, lens ident strings
